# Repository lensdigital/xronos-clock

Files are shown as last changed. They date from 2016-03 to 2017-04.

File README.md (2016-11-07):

Xronos (from greek Χρόνος [kronos] which means Time) Clock is not your average Alarm clock.  
It’s open source, hackable and customizable device.  
It has a stylish look, hand made, and it Talks! 
Heck it will even tell you temperature inside your room or from a remote sensor!
Xronos has internal backup battery that will allow it to keep time if you forgot to plug in … if it’s just for an hour or … for a year or two!  
All settings are saved to flash memory (EEPROM), so you don’t have to worry about power loss. All your alarm settings and preference will be there when power comes back on!
Since all audio files are kept on SD card inside, you can even change alarm tones, or replace voice prompts with your own
Xronos has 3 cool looking durable arcade buttons that give you simple access to all of it’s features.

Note: Please do not use V2 for Xronos 2 Clock anymore. V2 Firmware is no longer maintained, but V3 will work with Xronos 2 Clock as well as with upcoming Xronos 3 clocks.

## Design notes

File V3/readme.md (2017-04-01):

While there's no release date for Xronos 3 clock (I need financing to do a run of new LED displays), I rewrote most of the code and it's now compatible with Xronos V2!
*** Firmware V2 is no longer suppored to maitananed ***
What's new in V3 firmware:
- Supports both DS3231 and DS1307 RTCs chips
- DST and all US Timezones are now (finally!) supported (init EEPROM to write all TZ rules).
- Supports both RFM12b and RFM69w Trancievers (although RFM69w can cause clock to lock up due to SPI conflic with SD library)
- Radio settings (such as frequency, node IDs, etc.) can now be changed in Setup menu
- Most definitions moved to xronos3.h file for cleaner look
- Si7021 temperature and humidity internal sensor now supported
- Supports SoundZ library (audio playback from SPI Flash, only compatible with Xronos3 board). WaveHC no longer used by Xronos3 clock, only for Xronos2
- Button logic was rewritten, holding INCR button for 2 seconds will activate accelerated incrementation in settings of the time, alarm, etc.
To use code for Xronos 2.1 clocks, just uncomment "#define XRONOS2" from main file as well as HT1632.h 
You must initialize EEPROM to write all Timezone rules to it. Do it by either uncommenting initEEPROM() in setup function or thru the menu.
If using RFM12b library with Xronos 2 Clock, please repalce RFM12b.h file with file included in this repository
You will also need a timezone library (https://github.com/JChristensen/Timezone).

NOTICE: To compile code you need Arduino IDE 1.6.10 or higher. It won't work in previous versions.
To upload firmware hex file directly, you will need AVRDUDE version 6.3!

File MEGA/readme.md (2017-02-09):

Expermiental firmware for Xronos Mega Clock (Four 24x16 LED Matrix screens(single color), GPS)

Uploading instructions (Windows):
Upload via FTDI or similar USB to Serial adapter (6 pin).
You can either use Arduino IDE 1.6.10 with included sketch (make sure you have all required libraries)

To upload hex firmware:
  - copy AVRDUDE version 6.3 to know location (i.e. C:\Xronos\AVR). Are required files included with Arduino IDE 1.6.10
  - save all *.bat and *.hex files to some folder on your computer
  - modify update_xronos.bat and specify AVRPath and AVRConfig paths if different.
  - Run start_here.bat and specify COM port of FTDI adapter

Issues:
  - Currently (version 09) user options settings affecting scrolling are not working yet.
  - There might be issue with RGB LED indicator not working correctly
  - When settings hours, date might change, so always check date after settings hours. If you usign GPS, clock will set itself correctly.

GPS and Serial:
  PLease keep in mind that GPS uses same Serial (RX) port as FTDI programmer. This doesn't affect programming clock but please be aware of following limitations:
  - When FTDI adapter is plugged in, GPS will not communicate with clock
  - When GPS function is enabled in menu, you will not see serial output from clock (disable it to see debug info)

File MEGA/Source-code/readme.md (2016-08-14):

Arduino sketch, compatible with Arduino 1.6.10

Requires followign external libraries:
  - Time
  - DS1307RTC (same library works with DS3231 as well)
  - DallasTemperature
  - IRremote (not to be confused with Arduino Robot IR library)
  - TinyGPS
  - Timezone
  
Use following Hardware profile: 
"maniacbug" Mighty 1284p 16Mhz using Optiboot

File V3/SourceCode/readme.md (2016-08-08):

Arduino Source Code for Xronos 2/3 

Note this will only work with Arduino 1.6.10 and probably higher.

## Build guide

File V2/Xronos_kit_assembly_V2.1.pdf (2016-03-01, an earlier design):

# Kit assembly

# What's included:

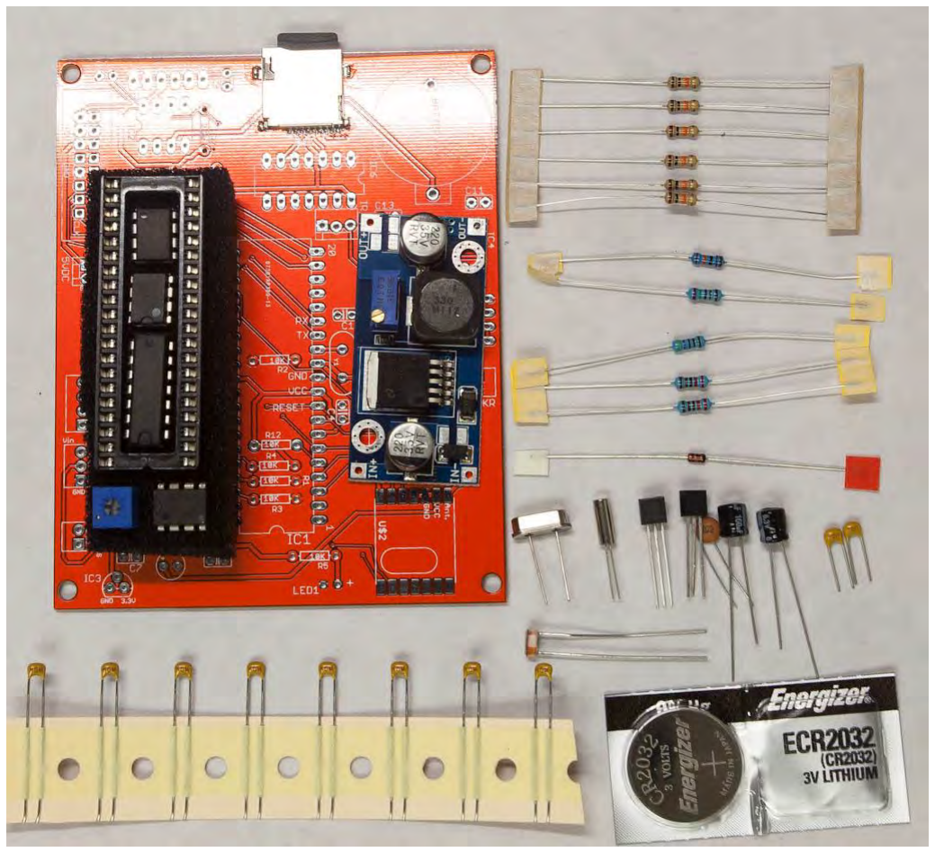
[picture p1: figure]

- Antistatic bag contains:
- ICs on foam block:
- ATMega1284p microprocessor w/ firmware (40 pin)
- 40 pin IC socket

- SN74AHC125N Quad buffer(14 pin)
- DS1308 RTC (8 pin)
- MCP4921 DAC (8 pin)
- TS922IN OpAmp (8 pin)
- Trim pot (10K)
- PCB Board w/ soldered microSD socket and 256Mb microSD card
- CR2032 3 V battery
- Power supply module
- 16 MHz Oscillator crystal

- 32.758Khz Oscillator crystal
- 2x100uF electrolytic Capacitors
- DS18B20 temperature sensor IC
- 3.3V volt reg IC (Yes looks almost identical to DS18B20)
- 8 pcs 0.1uF ceramic caps (104)
Can by two types. Either yellow “dipped”

or orange:

- 2 pcs 22pF ceramic caps
Can by two types. Either yellow “dipped”:

or orange:

- 0.01uF ceramic capacitor (103)

- Photoresistor
- Diode 1N4148
- 6 pcs 10K resistors (ceramic)
- 2 pcs 2.2K resistors (metal film, bluish color)
- 100K resistor (metal film, bluish color)
- 1.5K resistor (metal film, bluish color)
- 4.7K resistor (metal film, bluish color)
- Bag with headers:

- Battery holder
- 2x8 IDC box header
- DC jack
- 6 pin male pin 90 degree header (FTDI)
- 3 pcs 2 pin headers (for power, spkr, photo sensor)

- 4 pin header (for buttons)
- 3 pin header (for temperature)
- Small button (reset)
- Bag with nuts and bolts (hardware)
- 4 pcs 8-32 3-1/2" machine screws (longest screws in package)
- 4 pcs 8-32 Acorn nuts
- 9/16" 4-40 machine screw (longest of 4-40 screws)
- 4 pcs 1/2" 4-40 machine screws (slightly shorter than 9/16”)
- 10 pcs 4-40 5/16" machine screws

- 10 pcs 4-40 3/16" machine screws (shortest of 4-40 screws)
- 6 pcs 1/4" 4-40 alum hex standoffs (shortest)
- 4 pcs 3/8" 4-40 alum hex standoffs (longest)
- 5 pcs 4-40 hex nuts
- Cables:
- 2 pcs two color (polarized) 2 wire cables w/ plug (wires of various colors, one always striped)
- 2 wire same color cable (yellow) w/ plug
- 2 wire 2 color thick cable without plug
- 4 wire flat cable w/ plug (colors may differ)
- 3 wire flat cable w/plug (colors may differ)

- Single 6" wire (yellow)

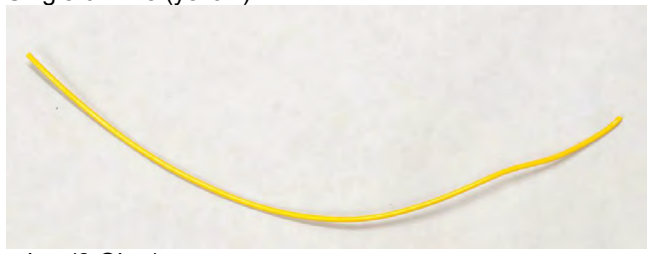
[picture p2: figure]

- Speaker (8 Ohm)
- 3 Arcade buttons
- Enclosure:
- Back

- Front
- Faceplate
- Top
- Bottom
- Left (maintenance door)

- Right (w/ speaker holes and DC jack hole)
- 16x32 LED Display
- DC Wall power supply
- Q-tips

Infrared Kit (Optional)
- 3-pin header
- 3 wire flat cable w/plug (colors may differ)
- IR Receiver (38kHz)
- Remote control

RFM Kit (Optional)
- RMF12B Receiver (915Mhz)
- SN74AHC125N Quad buffer(14 pin)

•
- 10K resistor
- Wire antenna

# PCB Assembly

Note: Some components (diode, electrolythic caps, ICs) are polarized and have to be inserted/soldered right way. Failure to do so will result in board damage!
Resistors and ceramic disk capacitors are not polarized and doesn't mattered which way solders.
Parts:
- All parts contained in antistatic bag (see “what’s included section for all parts descriptions and pictures)
- All parts contained in headers bag (see “what’s included section for all parts descriptions and pictures)

## Required tools/supplies:

- Good Soldering iron with small tip
- Resin core solder (thin diameter, i.e. 0.032”)
- Small Diagonal cutters (Xcelite are best!)

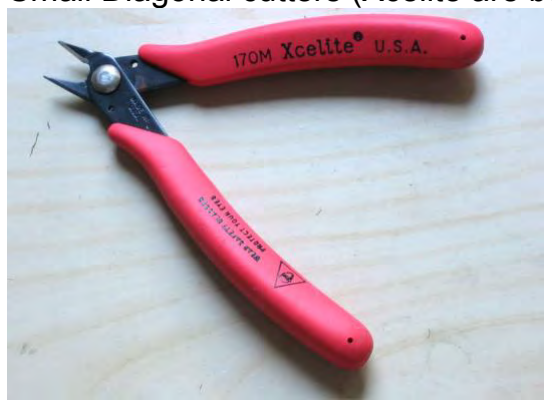
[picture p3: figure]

## Recommended tools:

- Locking metal tweezers. I HIGHLY recommend getting one if you don’t have it! One of the most useful tools during assembly. It will hold tricky components in place and take damaging heat away from ICs.

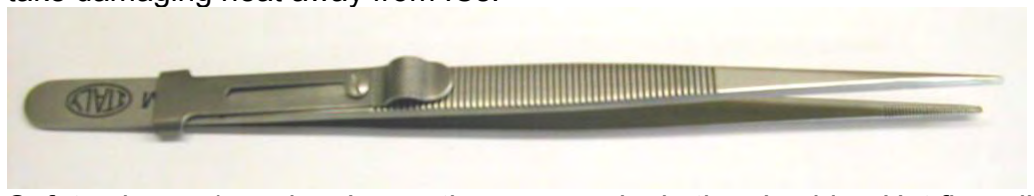
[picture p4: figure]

- Safety glasses/goggles. I wear them every single time I solder. Hot flux will splatter and can damage your eyes. You cannot replace your eyes!
- Wire stripping tool for small gauge wire (AWG24-30)
- Needle nose pliers
- Soldering vice or 3rd hand tool
- FTID Adapter (to check if your board is working in step 1
- Fumes extractor

Assembly process
Order you assemble board is up to you. I’ve organized in parts to make it easier to check your work and troubleshoot before you go too far. For example Part I describes minimum number of components needed to get microprocessor going which you can check with FTDI Adapter (not included). There’s nothing worse than spending 2 hours soldering everything and then finding out that you put a capacitor wrong way in Part II. Note: Only one 40 pin IC socket is included, however it’s totally ok to use your own IC sockets for other chips, as it will make soldering process safer and you’ll be able to reposition ICs in case you inserted it wrong way.
Part I: Microprocessor
1. Align 40 pin socket notch and insert into PCB. Flip around and making sure all pins are fully in solder 2 from opposite ends. Insert into wise and solder rest
Tip: Set iron to hot temp (374C) Solder in rows, clean tip after each row (20 pins)
2. 10K Resistors
1. Unpackage 10K resistors
2. bend legs at base to straight angle
3. insert to R1,R2,R3,R4,R9, R12 bending leads outwards after each so they stay in.
Note: It’s difficult to see R1 location because label is blocked by IC socket. R1 is located between R4 and R3. To make things easier ALL resistors that fit inside IC socket are 10K resistors!

4. Turn PCB around and solder all

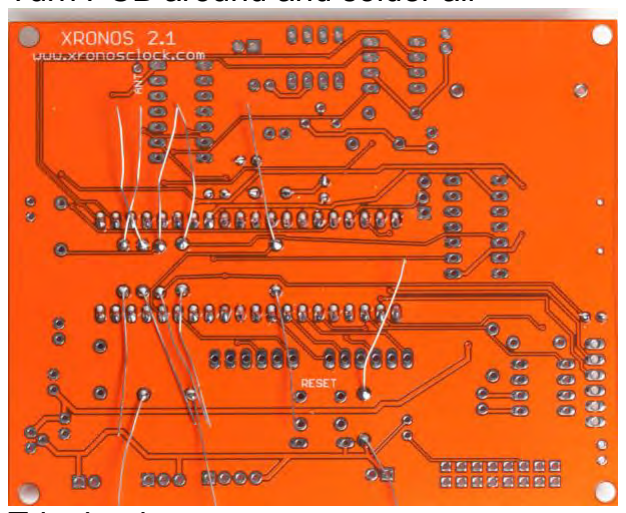
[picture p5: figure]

5. Trim leads
3. Insert Y1 16Mhz OSC
4. Insert C1 and C2 22pF ceramic capacitors (marked as 22 or 220)
5. Insert C3 and C4 0.1uF ceramic capacitors (marked as 104)
6. Solder above and trim leads

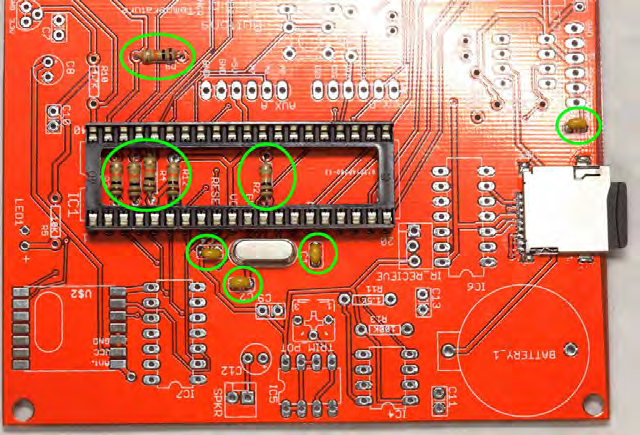
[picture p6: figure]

Picture above shows R1-R4,R9,R12, C1-C4 and Y1 soldered.
7. Take diode D1 and note which side has black ring! Alight it as marked on D1 silkscreen image, insert, bend leads, solder, trim. Failure to align it right way will prevent uploading firmware in the future.

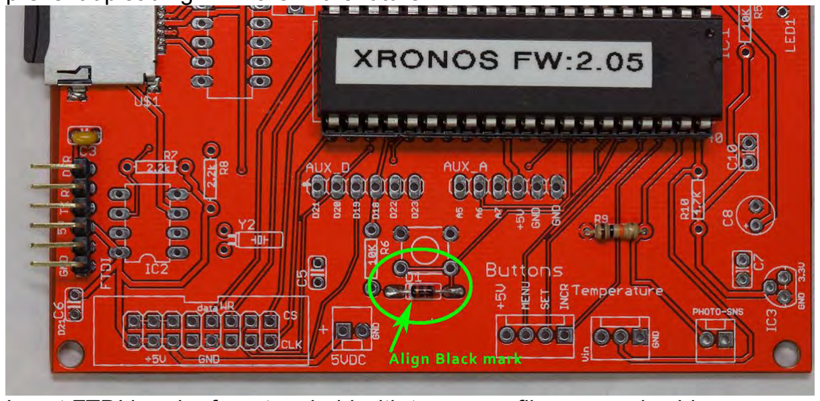
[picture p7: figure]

8. Insert FTDI header from top, hold with tweezers, flip over and solder
Tip: Use very high temp setting on iron, especially for ground pins.
9. Take microprocessor chip and bend all pins slightly inward so it will fit 40 pin socket. I usually hold it by edges, press one side of pins flat on the table and push slightly until the bend, just a tiny bit. Make sure you keep pressure even. Do this on the other side until chip’s leads align with socket holes.

VERY IMPORTANT, align chip correctly, first pin is where notch is, it should resemble outline on the PCB board. Now carefully insert chip and press evenly until it slides in. Look close to see if any bins bent or came out of socket (if you find any remove chip with chip extractor or flat screwdriver and straighten pins.
10.If you have FTDI adapter now is good time to check if board is working at this point. Connect it to computer and using serial monitor from Arduino IDE, or any terminal emulator program (set to 115200 baud and correct COM port) you should get message on the screen (i.e. RTC set system time. SD card error.). Don't worry about SD Card error, we didn't assemble all components for it yet :)

If you don’t see any message, and you sure your FTDI adapter is working, check if chip is aligned correctly. Check all components. Refer to schematic on xronosclock.com site. Or ask us on forum for help.
Part II: microSD reader and Audio
1. Solder C13 0.01uF (code103) ceramic capacitor. Please note this one is different from the rest of ceramic capacitors!!!
2. Solder 6 remaining 0.1uF capacitors (code 104) to C5, C6, C7, C9, C10, C11 Warning! C13 IS Different value! Do not solder 0.1uf capacitor there by mistake.

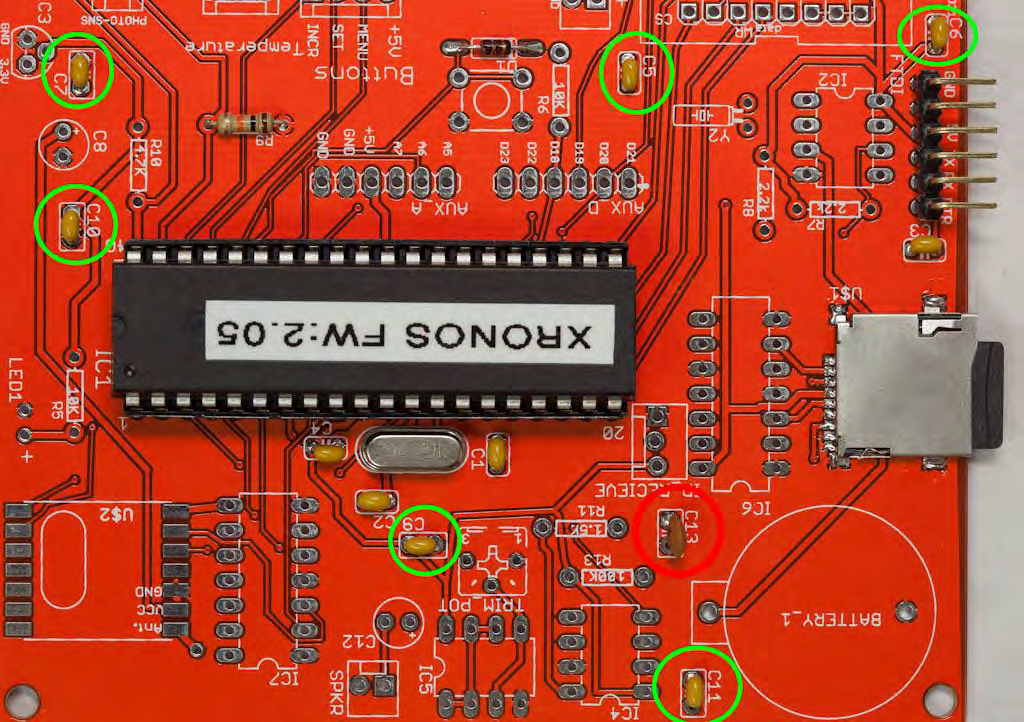
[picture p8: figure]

3. Now we'll solder 2 cylindrical electrolytic capacitors C8 & C12. They are polarized so make sure you put them right way. Longer leg is positive, insert into hole marked +. Negative part also has white stripe on the body. See picture below:
4. Now solder 3.3V voltage regulator to IC3. It looks identical to temp sensor, so read marking, it will say 1700. It's important to insert it right way, follow outline on PCB.
Warning: IC3 is sensitive to static, wear antistatic wrist band!
Warning: Do not overheat! Use lower setting on soldering iron (no more than 360

5. C)
6. Take Quad buffer chip IC6 (SN74AHC125N) and bend its legs slightly inward (just like with main microprocessor) until they parallel to each outer so it will fit the board. Pay attention to orientation notch, it's very important!

Note: It’s ok to use IC Sockets for all chips, but we don’t include them in the kit. Warning: IC is sensitive to static, wear antistatic wrist band!
Warning: Do not overheat! Use lower setting on soldering iron (no more than 360C) and/or use locking tweezers to hold it and conduct heat way.
7. Solder IC5 (TS922IN). Use same precautions as with above.
8. Solder IC4 (MCP4921). Use same precautions as with above.

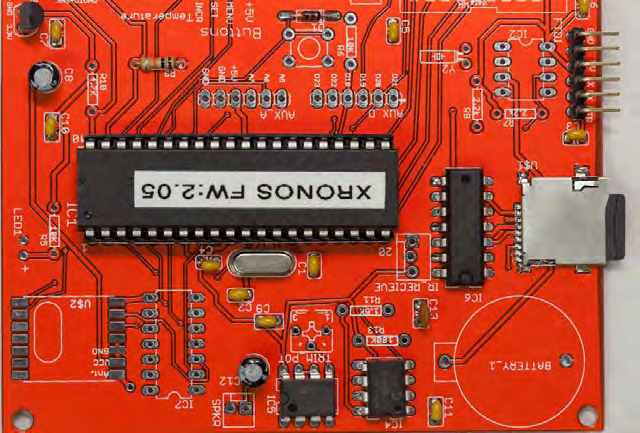
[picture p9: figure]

9. Insert and solder 3-pin blue trim pot
10.R13 and R11 are blue colored resistors. R11 is 1.5K (Brown, Green, Black, Brown, Brown) and R13 is 100K (brown, black, black, orange, brown). Solder these.
11. Next we will solder 2 pin header for speaker, and one for power (both marked on PCB). Take special attention at polarity of these, especially power connector! Smaller rectangle indicates plastic long back of the header. Note how power header faces way from edge of the board, and speaker go other way. See picture.

You can now test Audio! If you soldered connector to speaker and assembled power supply board (or you can power via FTDI) connect them and you should hear startup sound! Adjust volume by turning trim pot (clockwise for louder). Ideally bring it to full volume.
Part III: RTC and rest
1. Solder remaining 3 blue resistors:

1. R7 & R8 2.2K (red, red, black, brown,brown)
2. R10 4.7K (yellow, violet, black, brown, brown)
2. Solder Y2 socillator (small metal cylinder)
3. Solder IC2 (DS1307) RTC chip. Orient it correctly! I made mistake of soldering it wrong way once and it started to smoke!

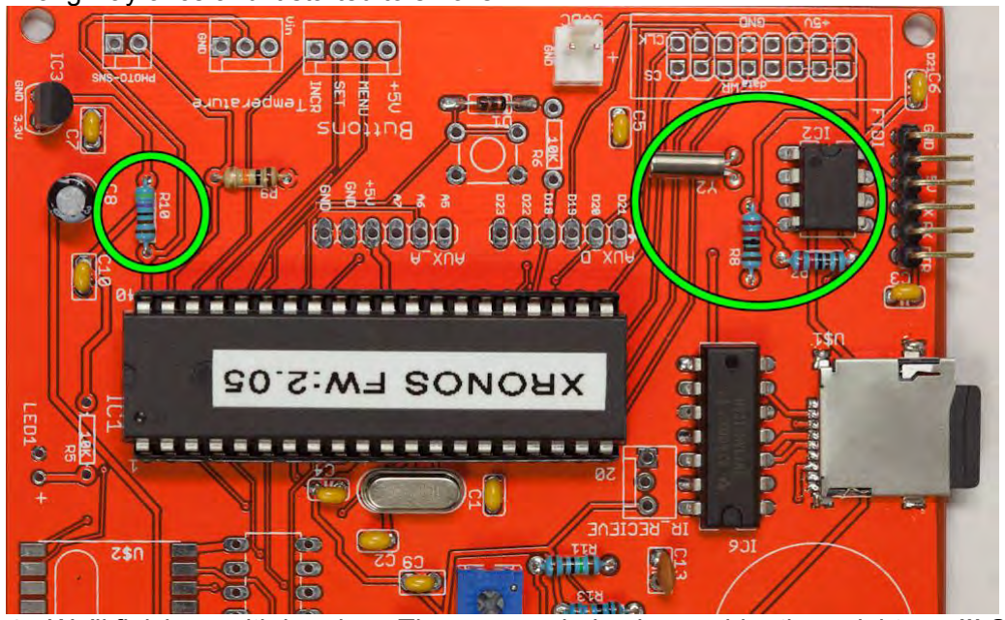
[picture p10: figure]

4. We'll finish up with headers. These are polarized, so solder them right way!!! Set soldering iron temp night, as these (especially IDC header) can be tough to solder. Also use locking tweezers to hold them in place.
1. Start with 2-pin Photo-sns header
2. Then do 3-pin (Temp) and 4-pin (buttons) headers next to it.
3. Solder big 8x2 IDC header
4. Solder battery holder. Negative terminal will require a lot of heat so set your iron to 390C

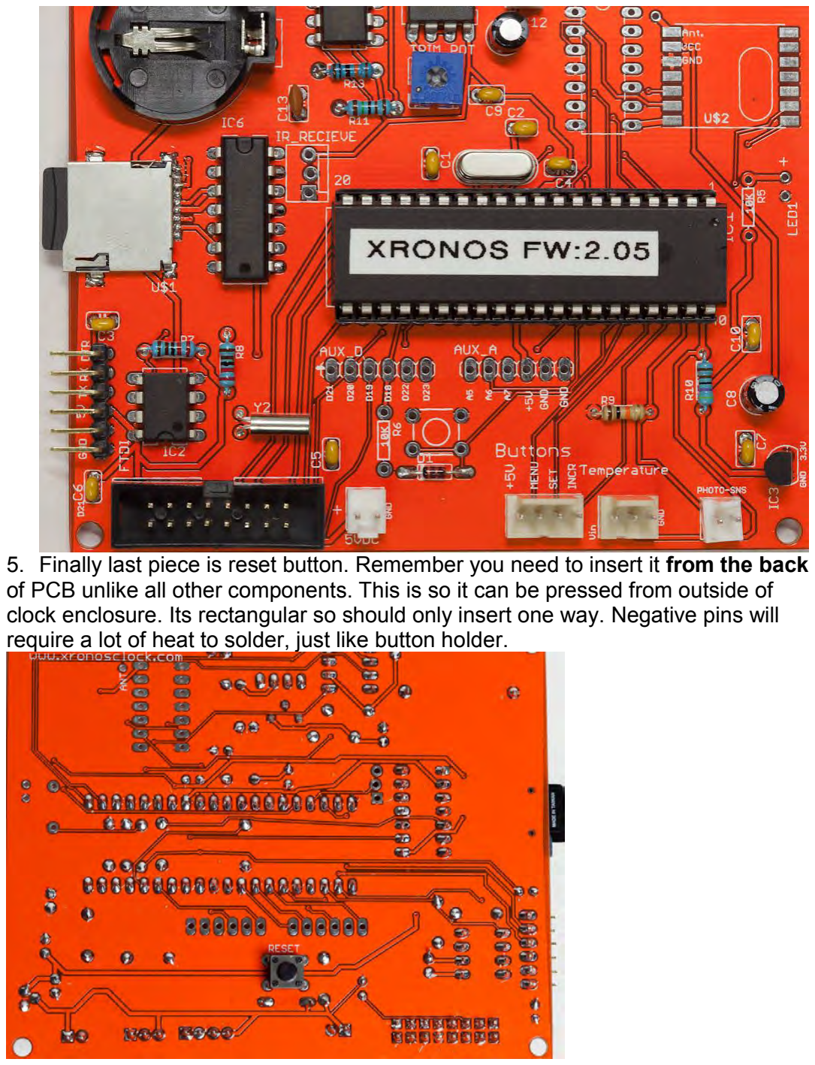
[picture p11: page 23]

5. Finally last piece is reset button. Remember you need to insert it from the back of PCB unlike all other components. This is so it can be pressed from outside of clock enclosure. Its rectangular so should only insert one way. Negative pins will require a lot of heat to solder, just like button holder.

Part IV: OPTIONAL RM12B receiver and IR receiver
Please note: You must have Firmware version 2.06 or later in order for these accessories to work!
1. Solder R6 (10K) resistor

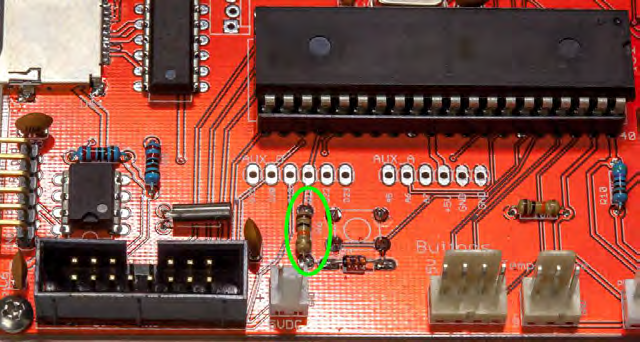
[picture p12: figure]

2. Note how bottom of RFM12B module will have an oval outline that matches one drawn on the PCB. You will follow that outline.
3. Do not place module on board yet. First put drop of solder on one of the pads on the PCB
4. Now place RFM12B module on board (following outline). Melt solder that you applied in step two and adjust module at the same time so all pads are aligned. Solder will hold it in place.
5. Now solder all pins.
6. Take Quad buffer chip IC7 (SN74AHC125N) and bend its legs slightly inward (just like with main microprocessor) so it will fit the board. Pay attention to orientation notch, it's very important!
Warning: IC is sensitive to static, wear antistatic wrist band!
Warning: Do not overheat! Use lower setting on soldering iron (no more than 360C)
and/or use locking tweezers to hold it and conduct heat way.

7. Strip wire antenna from one end and solder it thru “antenna” hole on PCB

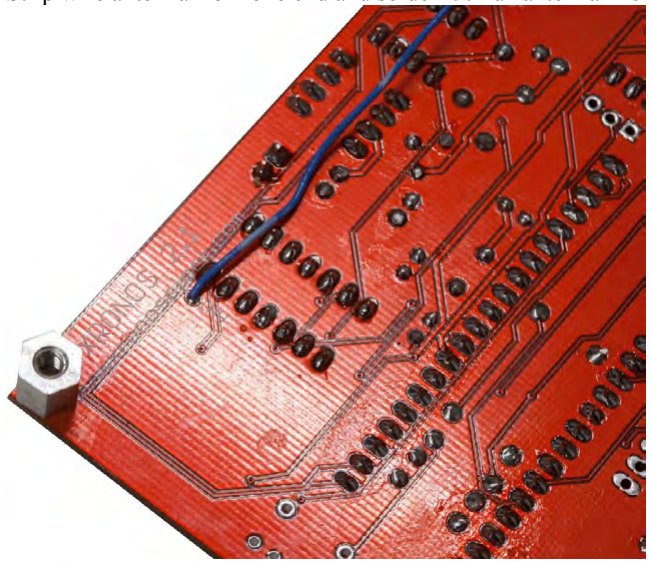
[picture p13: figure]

8. Finally if you purchased IR kit, solder 3 PIN header to IR_RECIEVE following board outline.

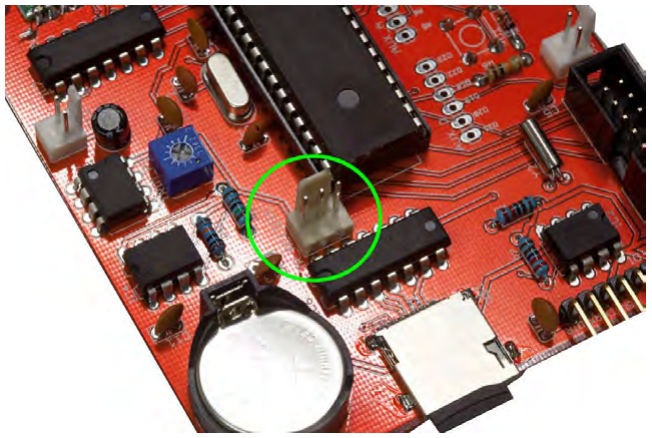
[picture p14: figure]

# Temperature sensor

1. Find black 3 pin cylindrical IC that's marked DS18B20. Note that it looks identical to 3.3V regulator in your kit so don't mistake one for another!
2. Shorten leads by cutting them off half way. Spread leads a little.
3. Set iron to lower heat and tin each lead
4. Take 3 pin flat and solder to sensor in correct order cable (colors vary, please check which pin goes where by following image below). Looking at flat face of the cylinder, left most lead is ground (despite it being marked with “+” on the chip), it goes to brown wire. Then rest will go in the order they are in the cable. Make sure you solder wires as parallel to the leads as possible. Pull slightly to make sure they are holding. You can also use heat shrinking tube if desired, but hot glue will keep them

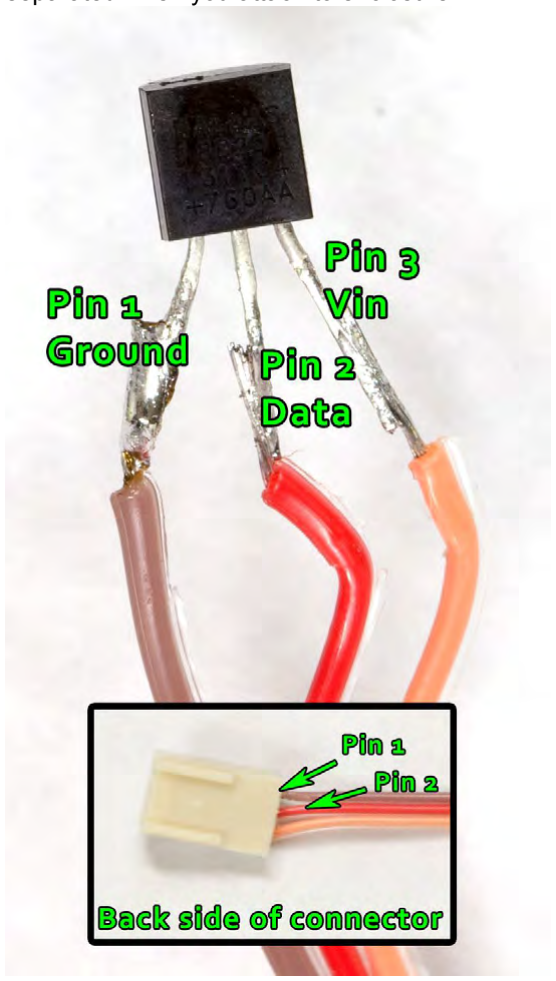
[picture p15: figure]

separated when you attach to enclosure.

# Power supply board

1. Take thick 2 wire two color cable, strip and tin both ends
3. Solder cable to DC jack as shown. If cable is Red/White, red will be positive. If its white and black, white is positive.

Note (on the pic above) how flat metal band is on the left side when positive terminal is on top.

4. Solder other two ends to power board to the IN part, using correct polarity.

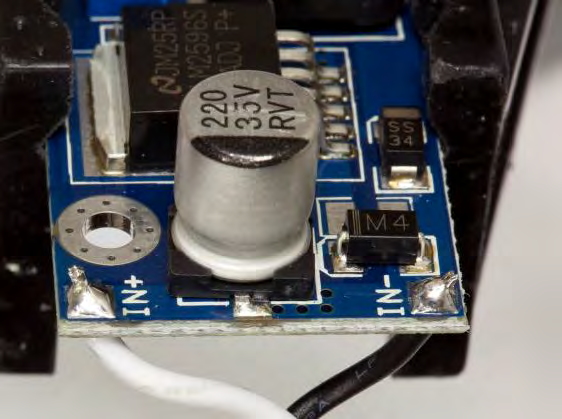
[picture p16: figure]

4. Take 2 wire two color cable (with plug already attached) and solder to the "OUT" holes on the power board. Solid color must go to OUT+, and striped to OUT-

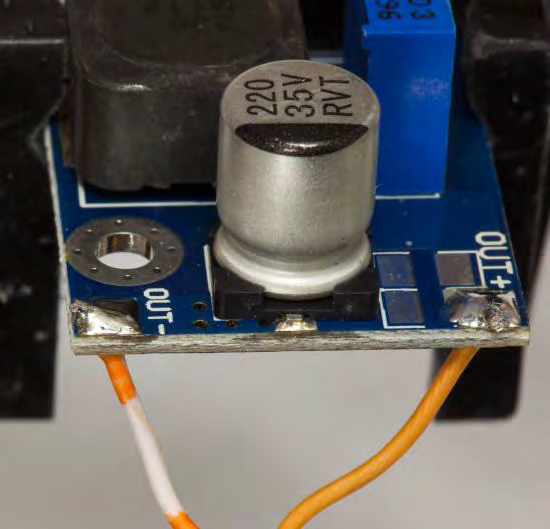
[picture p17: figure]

5. Plug dc wall adapter to DC jack and with multimeter verify correct polarity and output voltage of 5V. If voltage is off, adjust screw of the blue pot (blue block) with small flat screwdriver.

# Photo sensor

1. Trim leads
2. Tin leads
3. Take cable that has two wires of same color (yellow) and solder to photoresistor

# Speaker

1. Tin speaker leads
2. Take two color two wire cable and solder, with solid color wire going to +

Note: Some speakers do not have polarity markings! In this case solder as in picture above, negative wire on top, positive on the bottom.

Test board
Now is a good time to test your circuit board if you haven't.
1. Plug in speaker cable into PCB Speaker jack (on top).
2. Plug in power supply board into PCB power jack (marked PWR)
3. Connect wall DC adapter to DC socket. Clock should make startup sound.

IR Receiver (Optional)

1. Trim IR receiver’s 3 leads in half
2. As show in the picture below solder cable’s pin 1 to IR receiver’s pin 2 (middle)
3. Solder cable’s pin 2 to IR pin 1
4. Finally solder remaining wire.

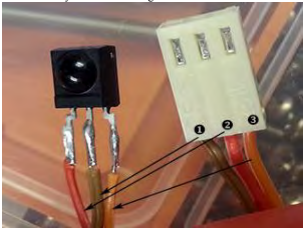
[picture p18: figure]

# Paint enclosure lettering

This is the most tedious part. You’ll need some patience but don’t worry, it’s not that hard You will need to get your own white Acrylic water based paint, as it’s not included in the kit. You can buy small bottle in local Walmart or arts supply store (I use Craft Smart paint (http://www.michaels.com/Craft-Smart-Acrylic-Paint-2oz/cp0396,default,pd.html) from Michaels) for about $0.50

1. Peel protective paper from both sides of top (button) panel
2. Gently scrape remaining paper from letters
3. Wet q-tip in water and clean laser etched letters
4. Squeeze paint to a pallet (piece of paper, plastic, etc).
5. Dip another clean q-tip to paint and start filling in letters. Make sure you completely fill in all crevasses but try not to leave too much paint in other areas.
6. Let it dry for few minutes.
7. Now take a piece of soft rug, wet it slightly with water and start wiping off paint. Only paint should be left is inside etchings. Take a clean dry piece of soft cloth and wipe haze left by damp cloth
Tip: I recommend using 2 pieces of soft clean cloth, while you can also use paper towel it might scratch plastic!
8. Repeat 5-7 at least one more time, until text is clearly visible and looks nice.
9. Now repeat steps 1-7 with back and right panels. These have less engravings so you might not have to fill them more than once like with top panel.

# Hot Glue

You will need to have a hot glue gun and some hot glue sticks for this. Any kind should work.
Before you begin keep in mind that:
1. All glue goes on the inside of the panels, not visible after you assemble enclosure.
2. When gluing speaker and nuts, avoid some areas that will jam enclosure. These are show in the pictures below as red rectangles. Good areas are show as green.
Tip: If you need to trim hot glue after it solidified use sharp razor blade. You can completely remove hot glue with heat gun (but keep in mind that speaker might get damaged by heat gun).
1. First glue speaker to inner side of right panel. Apply hot glue in several places but avoid areas shown in red on the picture. Green areas are good. And do not get any in the holes!

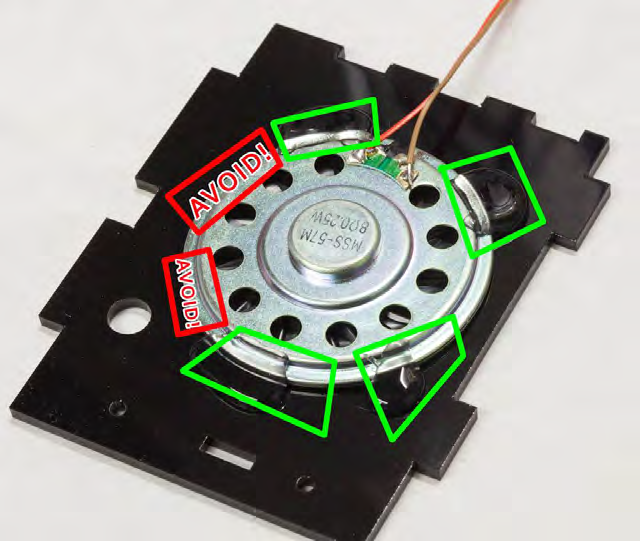
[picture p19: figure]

2. Set that panel aside to cool down
3. Insert temperature sensor into hole on back panel as shown (you must do it on inner surface). Put something under the panel (like a match) so sensor can protrude slightly outside. Bend leads and spread slightly so they not touching each over. Apply hot glue and let it cool and solidify.

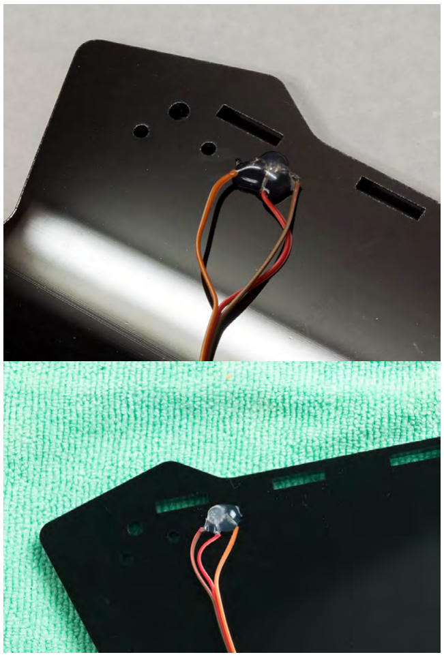
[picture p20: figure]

4. Glue photo sensor to top panel. From inside alight it with oval hole that’s shaped like sensor and try to level so it's flush with outside surface. Bend leads to opposite sides. You might want to use locking tweezers to hold one of leads. Apply glue. If you used tweezers after one side solidifies, remove them and apply glue to other side where tweezers were.

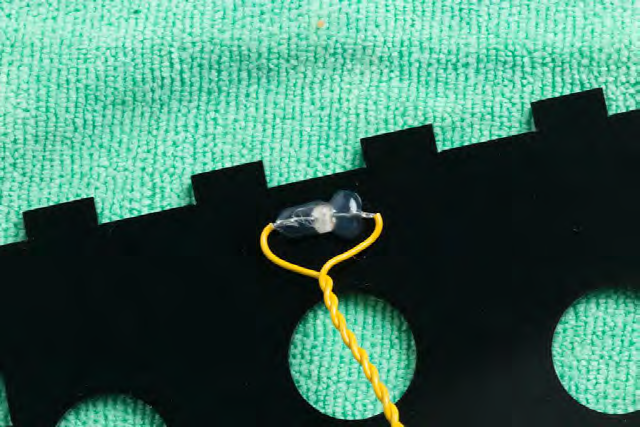
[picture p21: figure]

5. Now a tricky part - gluing 4-40 nuts. You can skip it, but it will be harder to assemble/re-assemble clocks if nuts are not held in place by hot glue.
1. Take bottom panel (one with ventilation holes) and note which surface is inner (it's marked!). Remove paper from that surface only!
2. Attach right (speaker) panel to bottom as shown, with two nuts and two 1/2 4-40 screws. On picture below I’ve indicated which way is front of the clock and which is back. See how bottom panel has only two tabs (this is front) and other side has four tabs (back). Right panel has two smaller tabs facing forward. This will help you identify to which side you need to place glue.
3. Attach left panel to button on the other side.

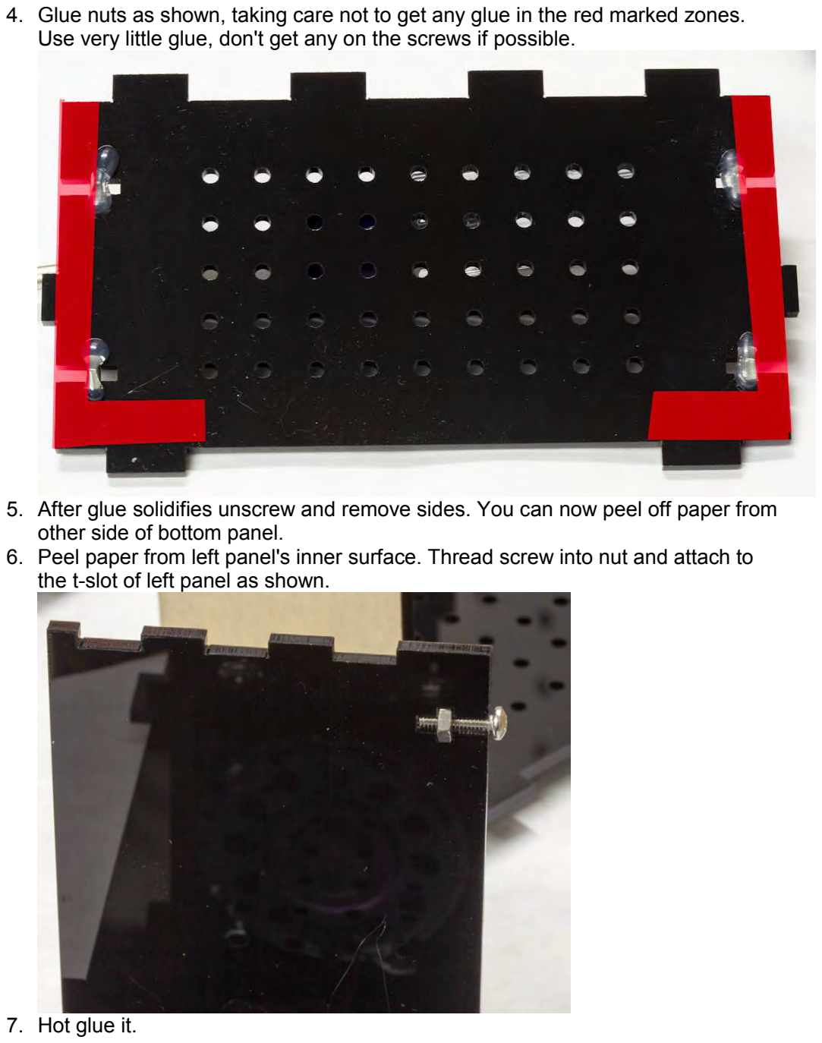
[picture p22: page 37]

4. Glue nuts as shown, taking care not to get any glue in the red marked zones. Use very little glue, don't get any on the screws if possible.
5. After glue solidifies unscrew and remove sides. You can now peel off paper from other side of bottom panel.
6. Peel paper from left panel's inner surface. Thread screw into nut and attach to the t-slot of left panel as shown.
7. Hot glue it.

Optional: RF Receiver

1. Locate bottom of the LCD panel (bottom is where all the plugs are).
2. Turn it around so LEDs are facing you and place large drop of hot glue just below LEDs
3. Just before it solidifies Place RF receiver (with attached wire) on top of it with round “window” facing you. Be careful not to get any glue on bulging part.
Final result should look similar to the picture above.

# Buttons

Note: Your buttons might looks slightly different depending on manufacturer. Some have contacts on opposite ends with 2 holes, some have contacts on same size in line with just one hole in each.
1. Cut single yellow 6" wire in half
2. Strip and tin ends, taking care to not leave too much solder on them (so they can easy go thru button round holes
3. Take middle (set button), thread both wires thru one lead (same hole) and solder. Cut off excess
Note: your button might not have hole large enough for 2 wires. In that case you will need to solder wires together and then to the button’s lead.
4. Insert all buttons into top panel (in the right places) until they snap in place.
5. Solder one of the yellow wires coming out of middle “Set” button to white “Incr” button’s lead.
6. Get 4 wire flat cable. By looking at plug determine which wire goes to pin 1 (usually violet or red). This is your +5V line. Next to it is menu, set and finally incr signal wires.

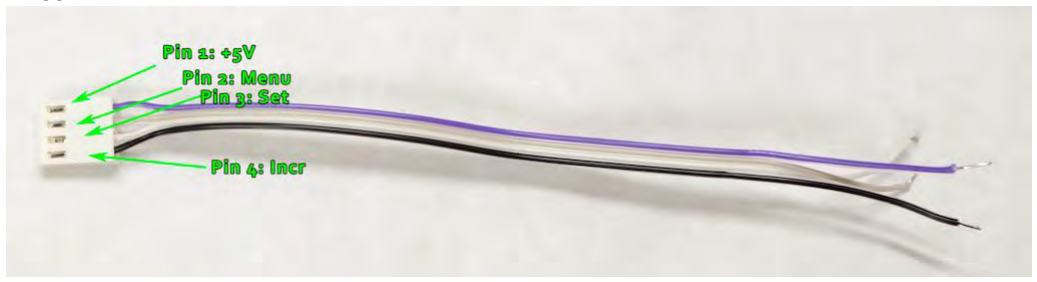
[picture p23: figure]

6. Insert pin 1 wire together with one of ends of yellow wire into same lead's hole of black "Menu" button and solder. You are basically connecting power line to all buttons.
8. Now solder "menu" wire to second lead of "menu" button.
9. Solder "set" wire to second lead of "set" button
10.And finally solder "incr" wire to second lead of "incr" button.

Prep circuit boards for mounting.

You going to attach aluminum hex standoffs to boards with 4-40 3/16" screws (they are shortest screws in the kit). Do not tighten any screws, leave them loose for now so standoffs cam move around slightly.
1. Remove LED screen from box and antistatic bag.
2. Peel off plastic squares from front surfaces.
3. Attach four 3/8" hex standoffs (longest ones) to the LED display with 4-40 3/16" screws. Standoffs should be on the front side.
4. Attach two 1/4" hex standoffs to power supply with 4-40 3/16" screws.
5. Attach remaining 4 standoffs to main PCB' back side
Mount LED screen
1. Pay close attention to front panel. Its hard to say where top and bottom or back and front is, so we marked it with arrow on the FRONT side pointing towards top. You will attach LED from opposite side. Bottom of LED is where connectors are.
2. Align it and remember how it should be.
3. Now take protective paper from BACK (unmarked) side. It is better to leave front masking paper on for now.
4. Screw it LED in through the holes with four 4-40 5/16" screws. Some screws might not alight with hex standoff holes. That's why we didn't tighten them. Move standoffs until screws fit. Tighten screws on both sides.
5. Now we can peel masking paper from front face. It's held by screws to, so star peeling until you close to 1st screw, unscrew it a little and you should have no problem peeling paper from under it. Once it's clear of paper, screw it back in, then do hex one, one by one. It's actually easier than it sounds.
Tip: You can skip this step and leave paper to protect clock face until enclosure is nearly fully assembled!

# Mount PCB

1. Align PCB as shown (temp cable under for better cable managment)
2. Screw to the back panel with four 4-40 5/16" screws. If any holes don't align move standoffs slightly.
3. Tighten all screws, but not too hard.
4. Plug in temp sensor.

# Mount Power Supply board

1. Align as shown (thick cable on top).
2. Attach to panel with two 4-40 5/16" screws
3. Unscrew nut from DC plug, insert plug into right (speaker) panel add washer and secure with nut.
4. Plug in 2 pin power connector to PWR plug on PCB.
Note: Speaker, Power and Light sensors have same kind of plugs on PCB. Make sure you use correct one!

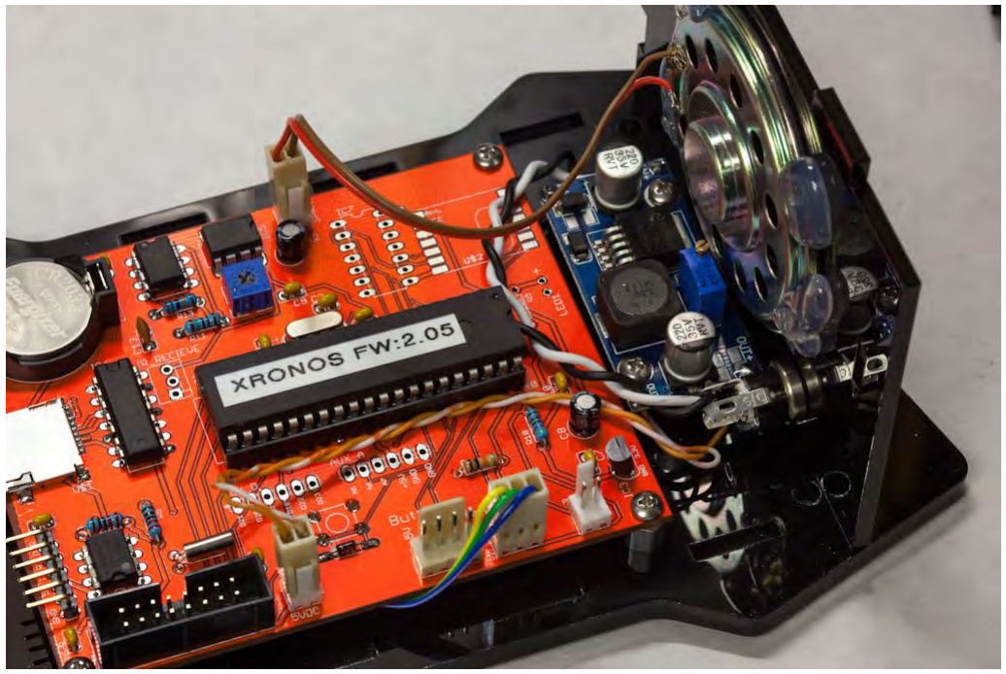
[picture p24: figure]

# Assemble enclosure

Warning! Acrylic is somewhat fragile. Do not force tabs into slots, you might break them.
1. Lay back panel on the table. You will insert all other panels into it.
2. Insert right speaker panel into slots
3. If bottom panel still has protective paper, peel it off.
4. Insert bottom panel into back and at the same time its tab should go into slot in right panel. You might have to lift right panel slightly for this.
5. Plug in speaker cable to PCB.
Note: Speaker, Power and Light sensors have same kind of plugs on PCB. Make sure you use correct one!
6. Secure right panel to bottom panel with two 4-30 1/2" screws. Don't over tighten, it's easy to crack acrylic here!
7. Insert top panel with buttons into bottom panel (you might have to raise right panel slightly to get tabs to interlock). Middle button might touch speaker plug. Rotate button slightly so it fits on top of plug, and check light sensor cable so it doesn't get sandwiched between button and plug.
8. Plug in button cable and light sensor cable into PCB
9. We will do left panel at the very end, don't worry about it, it's designed to be detached and re-attached when clock is fully assembled.
10.Take front panel with LED display, bring it close to the rest of case and plug big ribbon cable into PCB.
11.If you purchased IR Receiver plug it’s cable into IR header.
12.Gently slide front panel over until all tabs are in the slots. Do not press hard on it, it should go down effortlessly once everything aligned (wiggle various panels). Tabs will not protrude all the way, that's normal, just check from sides that its sitting ok. If display doesn't go all the way down and " squeaking" it means that hot glue holding nuts on the bottom panel is in a way. You can probably see it from left side. If that's the case you'll need to take bottom panel out and trim glue with blade.
13.Take faceplate, peel masking tape and put faceplate on top of front panel. You might press on it slightly so screws will "click" through openings.
14.Take 4 longest screws (8-32 3-1/2") and thread from the bottom, securing on top with acorn nuts. Easiest way to do it is hang one corner of Enclosure from table edge, insert screw, then expose next corner, etc.
Note: If crews experience much resistance it could be that hot glue holding nuts on bottom panel is on the way. You can either try threading screws thru the glue with screwdriver or trim glue with blade. Ideally these long nuts should go thru enclosure very easy.

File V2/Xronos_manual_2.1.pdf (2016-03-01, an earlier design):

# Xronos Clock Manual

For Xronos Clock V2.1

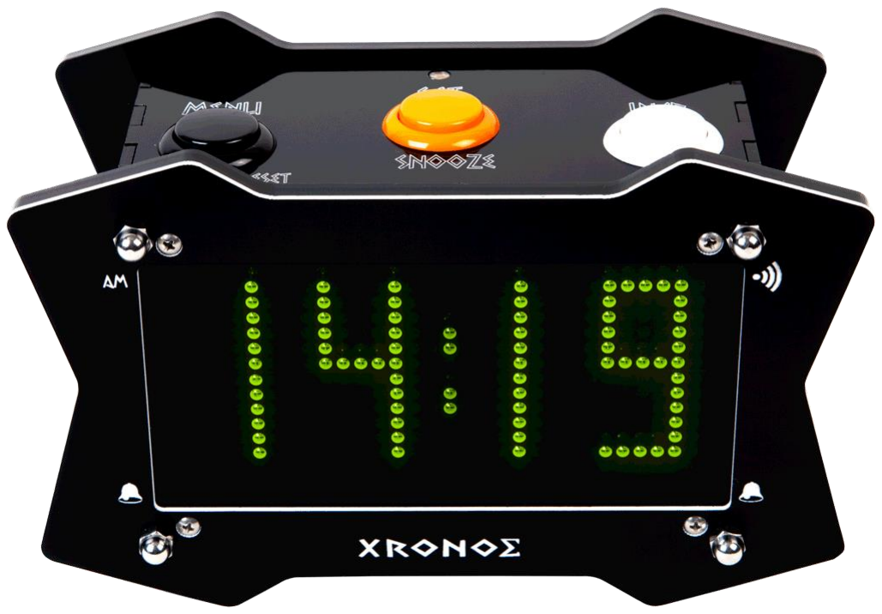
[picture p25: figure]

Foreword.

If you are like me, you’ll probably ditch this manual and start messing with cool arcade buttons. Xronos clock is intuitive and should be easy to figure out. But I see you are still reading, so let’s get on with it, I promise I’ll try not to make this manual look as boring as your average table saw instructions.

Quick start

Xronos clock comes with a good quality AC Adapter that will power your clock and won’t waste too much of power!
Firmly plug in power adapter into wall outlet and DC cable into clock’s right side. Assuming delivery man didn’t drop your package off the truck (is there anything rattling inside clock case?) and you have power in your house Xronos should greet you with scrolling welcoming message and firmware number. If you are real lucky it will even play a startup melody :)
But not to worry, if startup sequence starts to drive you crazy in the future you can turn it off!

Let’s get familiar with Xronos Clock.

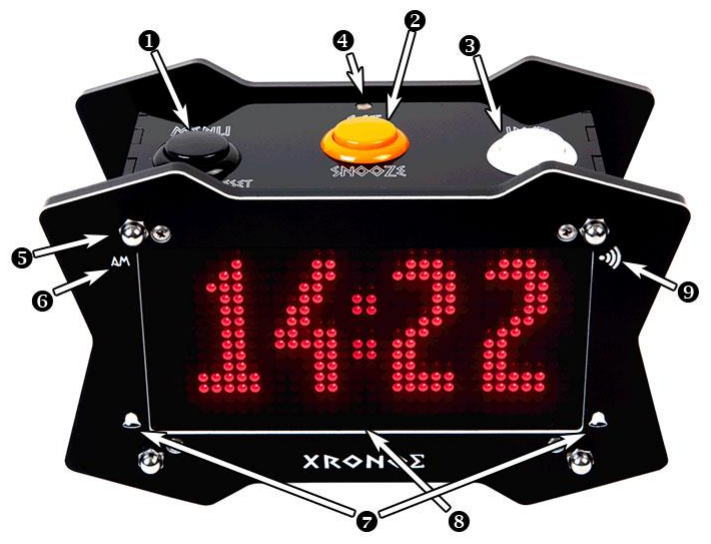
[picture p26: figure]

1 – MENU/ALARM RESET BUTTON 2 – SET/SNOOZE BUTTON
3 – INCR/TALK BUTTON
4 – AMBIENT LIGHT SENSOR
5 – ACORN NUTS (HOLDS ENCLOSURE TOGETHER) 6 – AM INDICATOR (FOR 12 HOUR MODE)
7 – ALARM 1 AND 2 INDICATORS
8 – IR SENSOR WINDOW (NOT SHOWN ON THIS PICTURE) 9 – RFM12B RECEIVER STATUS INDICATOR

Looking at the top of the clock you will find 3 very sleek looking arcade buttons. From left to right they are: MENU, SET and INCR (or Increment), and... well that’s it! What did you expect, a QWERTY keyboard? Each button has several functions.
Go ahead, touch the MENU button! Nice huh? Do it again! AGAIN!!!! :) Ok stop stop. MENU is primary button that will get you into a … *surprise!* menu system. With every press it will go to the next menu item and eventually back to the 1st. There’s no exit out of menu system per say, but don’t panic! If you stop pressing all buttons clock with automatically exit after 5 seconds of inactivity.
After you got into the menu that you want, press SET button to switch between items inside this menu. Then use INCR button to make change to selected item. And no need to “save” settings. All changes are saved into permanent memory (EEPROM) either immediately after pressing INCR button or after clock exits from menu.

Now look at the right side. It’s the one that has a lot of small holes. That’s for the speaker, next to it is opening for power plug.

On the back side, there’s an opening for resetting clock and temperature.

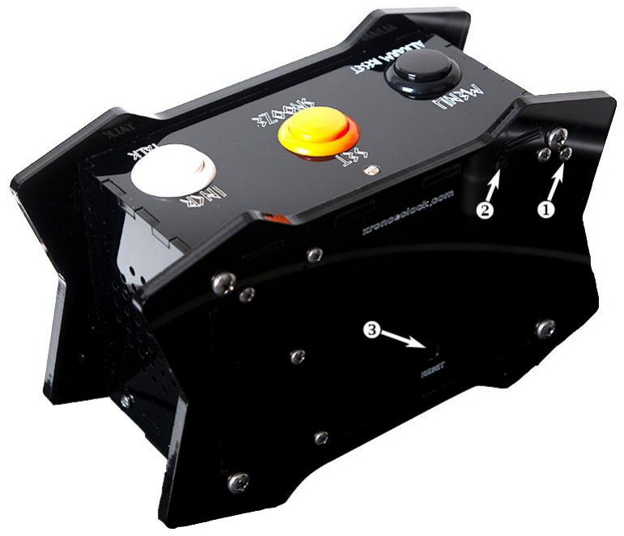
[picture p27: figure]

1 – MAINTENANCE DOOR RELEASE SCREW 2 – TEMPERATURE SENSOR
3 – RESET

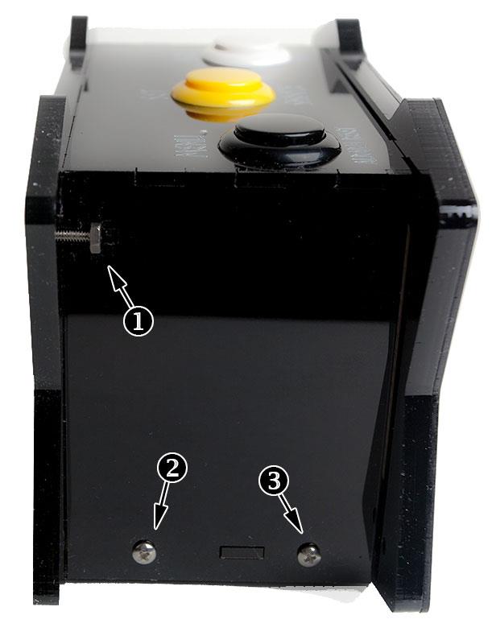
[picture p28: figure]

Left side of the clock has removable panel (held by 3 screws) for easy access to clock interface in case you want to re-program/update firmware, access microSD card (that holds all audio files) or replace clock battery. Yes, clock has internal small coin type battery for keeping time when external power is not available. It should last few years when in use, and much longer than not in use.

Setting Time (and surviving apocalypse)

After everything is up and running first thing you’ll might want to do is to set correct time and date. Out of the box clock is set to 24 hour (a.k.a. military time) mode. If you are more familiar with 12 hour mode (AM/PM) sorry, you are out of luck. Just kidding :) You can change modes by pressing MENU button until you see Settings on the screen. Press SET button. First option will be 12/24 hour mode. Press INCR button to change it if needed.

Hint: When you see something is flashing it means its selected and ready to be changed with INCR button.

Press MENU button again several times until you see Date/Time on the screen. Press SET button to select Hours/Minutes, etc. and INCR button to change it. Don’t fret if you accidently went over current year! Once you hit year 2040 it will go back to 2013. Why 2040? What a silly question! That’s when either world will end or Xronos Clock will become self-aware and will no longer need you (which is the same thing). So please be nice to it.
That’s it, now you should have a grasp of how menu system works, and at the end of the manual you will find especially boring fun schematic of all the menu functions and flows, sorry no pie charts.

Secondary Functions

As I mentioned earlier (were you paying any attention or just mashing arcade buttons?) each button has secondary function. Heck some have even more than 2! Xronos clock is practically Swiss army knife of clocks! Well not really a knife, and not Swiss, but it’s still pretty versatile! Most notable is the INCR button a.k.a. (we have ways of making you) TALK button. When not in any menu pressing INCR button will make Xronos Clock talk. Sorry it probably won’t be most engaging storytelling, but it will tell you current time, date, inside temperature and even what your alarms are set to!
Just briefly press and release this button to hear next item. If you pause for more than 6 seconds between presses it will go back to 1st item (i.e. current time). You can also hold INCR button for 2 or more seconds and once you release it clock will go into continuous talk mode meaning it will tell you time, date, temperature and alarm settings without you having to press button after each item. What you clock says is customizable via User Options menu. There you can choose what you want Xronos to say or not to say. For example you can set it to tell you only date and temperature, but not Time and Alarm settings.
When alarm sounds INCR button can also be used to turn on “please just few more minutes” Snoozing. Actually SET button also turns on Snooze. Either one will let you catch some more zzz’s. That’s pretty much all this “SAD” SET button does when not in the menu :(

Menu button also has secondary functions. You can use it to interrupt scrolling Info Display, and Reset Alarm for current day. Resetting alarm only works if Alarm is currently playing or snoozing.

Alarm Functionality

Your Xronos clock has mighty Dual Alarms.
Each can be set to sound either Daily (Sunday-Monday), Workdays (Monday thru Friday) or on Custom days of your choosing.

Warning: Never set both alarms to same time on same day! If you do, miniature black hole will form 5 centimeters above the clock and will probably transfer you and the planet into 37th dimension. Because time flows in reverse in 37th dimension, clock might not function as expected.

Each Alarm has LED indicator (dot on the bottom left and right of the LED screen). When light is green it means no Alarm is set for current day. When it’s orange Alarm is set for this day (keep in mind light will remain orange thru the day even if alarm already sounded and has been reset). Alarm light will be Red when Snoozing is activated.
Snoozing will silence alarm for 9 minutes, after which it will start sounding again until either Snooze or Reset engaged (i.e. via MENU button). Alarm will reset itself after 1 hour has passed or second Alarm kicked off.
Alarm menu system is slightly different from other menus, and requires master’s degree in nuclear dentistry to fully comprehend. If you set alarm to Custom mode, it will keep going thru Days of Week on the screen until you press INCR button when EXIT is shown. At this point you’ll be able to set alarm time and tone/melody.
There are currently 10 alarm tones/melodies to choose from. First 5 are of escalating type, meaning they will start at low volumes and get louder with each repeat of the sound (eventually reaching ultrasound frequencies, shuttering glass windows, and waking up every dog in the neighborhood *just kidding*). This is best way for a gentle wake up.
Last 5 alarm sounds will always start at full volume, you’ve been warned! :)

Info Display

Periodically you will see a message scrolling across the screen. This is your Info Display. It will briefly tell you date, temperature, alarm settings, winning lottery numbers and last 4 digits of your cat’s social security number. Well not really, just 1st three items. You can customize how frequently you want to see this via User Options menu. You can even turn it off completely. Info Display scrolling can be interrupted any time by pressing MENU button (what a neat button, huh?).

System Settings Menu

From here you can control many “under the hood” global functions of the clock such as setting 12/24 hour mode, Brightness (manual or automatic), color, clock font, sound volume, Fahrenheit or Celsius temperature mode, turn on/off optional RF and Infrared receiver functionality.

User Options Menu.

Very similar to System Settings. In this menu you will be setting misc. options such as what clock will say when TALK button is pressed, or how frequently Info Display will appear and temperature offset. See below about this option.

Temperature Offset

What is it and why it’s needed you might ask? Can it reverse effects of the global warming? Well you see, Xronos Clock components generate some heat. Especially LED matrix. As efficient as LEDs are they still get warm. Higher brightness you will choose, the warmer clock will get inside. This is really nothing to be worried about (we are talking about few degrees above ambient), however because temperature sensor is embedded in the clock case, it will usually show temperature couple of degrees higher than air in your room. Thus comes Temperature offset to the rescue! I recommend setting it to about -2 degrees. If you have another thermometer available use it to calibrate Xronos Clock to a correct temperature using offset.

Optional Features

In order to keep price of the clock down some extra features are available only as add-ons. Currently there are two features: Infrared Remote and RFM12b (radio frequency) transceiver.

Infrared Remote

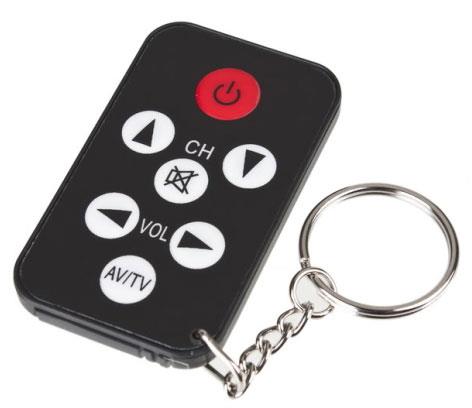
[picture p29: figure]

New to Xronos Clock 2.1 is support for Infrared Receiver and ability to control clock functions with “keychain” remote control.
Remote duplicates functionality of the arcade buttons and additionally gives ability to decrement items (i.e. when setting time you can increase or decrease hours/minutes).
Here’s what each button do:
- Big Red On/Off button: Same function as MENU button
- Mute (crossed speaker) button: Initiates TALK function (announce Time/Date, etc.). Additionally this buttons when held for few seconds starts to reprogram remote. More on this later.
- Up/Down “CH” buttons: Same function as SET button
- Left/Right “VOL” buttons: Decrement (new feature) or Increment (same as INCR) button functions
- AV/TV button: Initiates Announce All Items (same as holding TALK button for longer than 2 seconds).
Reprogramming:
Remote uses one CR2032 coin battery that should last you a long time. However if battery is replaced or accidently remodeled, remote might lose its programming and will stop controlling Xronos clock. Fortunately you can reprogram it. This requires some patience and a little tricky but can be done. Here’s procedure:
1. Disable InfoDisplay (Texts scrolling) function by going to User Menu->InfoDisplay and set frequency to “Never”
2. Make sure that at least one Talk Item is on (i.e. time announcement)
3. Point remote towards face of the Xronos Clock
4. Press and hold “Mute” button on the remote.

5. At this point remote enters programming mode and will cycle between different IR codes know to it. As soon you hear clock start talking release Mute button immediately.
6. Press On/Off or Mute button again to see if remote found right code. If nothing happens you skipped the right code and you’ll need to start process again from step 3. Usually on second try you will find right code almost immediately, but if you skipped too far you’ll have to hold button for several minutes until it cycles back thru all the IR codes. I know this part can be frustrating but unfortunately it’s the only way.

RMF12B transceiver
Another optional accessory is RFM12B chip which allows Xronos clock to receive (and possibly) send data over 915Mhz (or 413Mhz) frequency from/to sensor/device that’s also has RFM12B chip. As of this writing we do not have any accessories for sale that will work with RFM12B chip, but you are welcome to make your own. Out of the box Xronos clock supports remote temperature and humidity data. If you want to build your own sensor use Arduino code provided on our website (xronosclock.com).
If you are maker possibilities are endless. Here are few ideas:
- You can connect your own RFM12B based transmitter to computer and with right code you can send RSS feeds, emails, tweets, etc. to the Xronos clock (of course some coding will be required).
- Make several Xronos clocks talk to each other, or synchronize from external time source (i.e. GPS reciever).
- Build mailbox sensor and make your Xronos clock display alert when snail mail is reiceved.
We hope to release outdoor battery powered sensor some time in 1st half of 2014.
Things to keep in mind. You must reset/unplug your clock if you turn RF Setting on or off.
When RF is enabled, RF indicator (in top right corner) will be showing status of received data. If no data received after clock reset it will be RED. When receiving data it will turn green briefly and when go off. If no data received for over 30 minutes it will become RED again.
Keep in mind that no radio data can be received when clock is playing audio (i.e. alarm sounds, time is announced, etc.)

Complete Menu System Reference

Set Alarm 1: Controls 1st alarm

- On/Off : I’ll let you guess what it does :)
- Alarm Frequency:
- Custom: Let’s user choose any combination of days when alarm will sound ■ Mon: Y/N
■ Tue: Y/N
■ ....
■ Sun: Y/N
■ Exit: This option will exit day selection and goes to following time
- Daily: Alarm will sound every day
- Weekdays: Alarm will sound on usual workdays, i.e. Mon-Fri
- Alarm Hours/Minutes: Let’s you select time when alarm will sound
- Tone: Select Tone/Melody that’s played back as alarm. Tones 1-5 are escalating, 6-10 are played at full volume

Set Alarm 2 : Controls 2nd Alarm (Same options as above)

Time/Date: Sets current Time/Date

- Hours/Minutes
- Day/Month/Year (maximum Year allowed 2040, after which it goes back to 2013)

Sys Setup: Sets global clock settings

- Mode: Choose 12 hour (AM/PM) or 24 hour clock mode
- Brightness: Select LED display brightness from Night (lowest) to Max (brightest)
- Color: Sets Clock Color. Choices are Green, Red or Orange
- Font: Select Font of Main (big) clock display.
- Temp: Chooses temperature units. F = Fahrenheit = Celsius
- Sound Vol: Volume of System sounds and announcements. Does not affect alarm volume.
- Startup: Turns on/off startup sequence when clock is reset or powered on
- RF Sensor: Turns on/off optional RFM12B sensor. Reboot required.
Warning: Do not turn on if you don’t have RFM12B chip installed!
Warning: You must reboot/reset clocks if you turn this feature on or off.
- IR Receiver: Turns on/off optional infrared remote accessory. Reboot required.

User Menu: Sets User preferences

- Info Display – Controls what and is shown in scrolling text line and how frequently.
- Show Every: Controls frequency of Info Display, disables it and lets you select which item to show.
- Displ Date: Y/N Option to display date
- Displ InTemp: Y/N Option to display temperature form internal sensor
- Displ Extemp: Y/N Option to display temperature from optional external sensor. This item will not show up if RF sensor is turned off.
- Displ Alarm: Y/N Option to display alarm settings
- Displ RFStat: Y/N Option to display last time data from option external RF sensor was received. This item will not show up if RF sensor is turned off.
- Displ Humid: Y/N Option to display humidity data from optional external sensor. This item will not show up if RF sensor is turned off.
- Exit
- Talk Items
- Say Time: Y/N Option to announce Time when “TALK” button is pressed or held
- Say Date: Y/N Option to announce Date when “TALK” button is pressed or held
- Say InTemp: Y/N Option to announce Temperature from internal sensor when “TALK” button is pressed or held
- Say ExTemp: Y/N Option to announce temperature from option external sensor when “TALK” button is pressed or held. This item will not show up if RF sensor is turned off.
- Say Humid: Y/N Option to announce humidity data from option external sensor when “TALK” button is pressed or held. This item will not show up if RF sensor is turned off.
- Say Alrm: Y/N Option to announce Alarm settings when “TALK” button is pressed or held
- Exit
- Temp Offs: Sets negative offset to current temperature from internal sensor.

Maintenance and Hacking

Depending on preference your Xronos Alarm Clock should be wiped from time to time to remove accumulated dust. Or not. Other than this, you might have to occasionally change internal clock battery in case you notice clock loses time if there was power interruption. Xronos takes generic CR2032 coin type 3V battery.

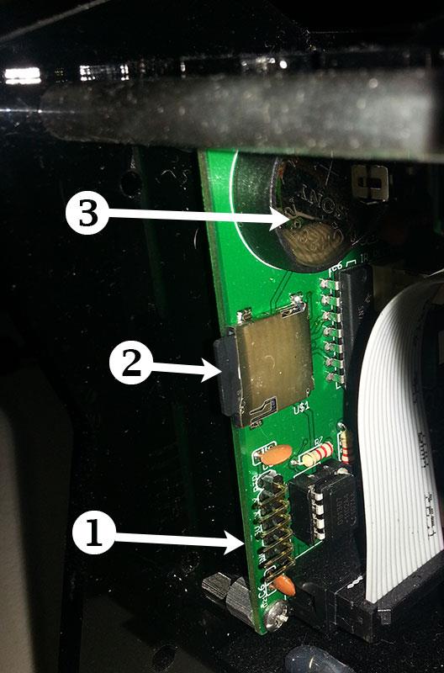
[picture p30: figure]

1 – FTDI Pins (for updating Firmware and communicating with clock) 2 – microSD Card (for changing audio data or Alarm tones)
2 – CR2032 Battery

Battery replacing procedure

To replace battery you will need a small Philips head screwdriver to open maintenance door on the left side of the clock. Here are steps to open maintenance door:
1 Unplug your Xronos Clock.
2 Looking at the front of the clock maintenance door is on the left of the clock (opposite from speaker side) held by 3 small screws (as shown on the picture above)
3 Gently remove screw that holds door from the back of the clock (1).
4 Unscrew two screws (2,3) on the bottom of the maintenance door. These are a little shorter than the screw you removed from the back. Try not to mix them.
5 Door should now come off easily, it’s only held by the tab on the bottom.

6 You should see internal battery. Using small flat screwdriver gently push metal retainer clip outward until it releases battery.

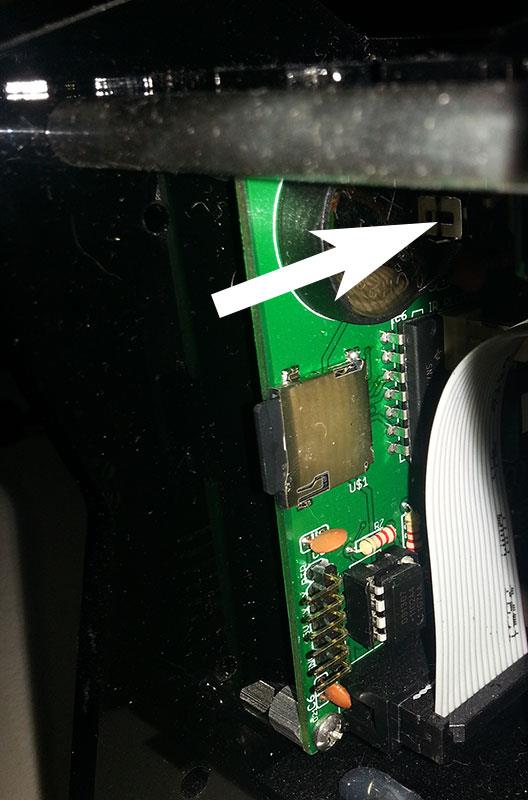
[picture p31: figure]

7 Replace with fresh battery. Insert it from plastic end opposite to metal clip first, and then press down until retainer clip clicks holding it in place.

Upgrading Firmware

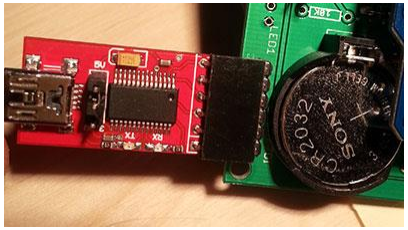
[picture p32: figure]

Removing maintenance door will also allow you access to the FTDI programming interface. You will need a 5V USB FTDI adapter board or cable (you can get one on Sparkfun or eBay). Make sure you unplug external power first. FTDI will provide power to the clock from your computer via USB. Please take care of plugging FTDI adapter correctly. Usually it means facing up (as show on the picture). Just look and match writing next to the pins (i.e. DTR on the far left, Ground on the far right).

There are basically two way to upgrade firmware, a simplified and advanced.

Simplified will require you to download AVRDude program, batch file and a hex file containing firmware.
For more advanced you will need Arduino IDE environment, required libraries and hardware files for Sanguino bootloader.

Whichever way you prefer you will still need to get FTDI adapter and install drivers for it! Firwmare is available at: http://www.xronosclock.com/ (go to Support and then to Technical Data and Downloads)

Simplified upgrade procedure:

1 Download avr.zip and extract it to your hard drive (i.e. to c:\xronos)
2 Also download update_xronos.bat file and latest HEX file with firmware. Copy both somewhere (i.e. c:\xronos)
3 Plug in USB cable from your computer to FTDI adapter and connect FTDI adapter into Xronos clock. Provided you installed drivers, your computer will acquire a COM port. 4 Take a note of the COM Port number by going Device Manger (via Control Panel -> system or right clicking on “Computer” icon on your desktop). Under Ports you will see USB Serial Port. Note it’s COM number (i.e. COM3)
5. Edit update_xronos.bat script (i.e. in Notepad)
Find two lines that specify path to AVR that you extracted in step 1: SET AVRPath="C:\Xronos\avr\bin\avrdude.exe"
SET AVRConfig="C:\Xronos\avr\etc\avrdude.conf"
And change to your actual file location
6. Open command prompt, navigate to the folder where you firmware scripts and run “start_here.bat”
7. You will be prompted for COM port, so put number you got from step 4.
8. If everything goes fine, you will see update progress and screen will turn green at successful upload.

Advanced upgrade:

1 Install latest Arduino IDE
2 Download Sanguino or Mighty 1284p hardware files and copy to your projects_home\hardware folder
3 Download and install libraries:
a Time
b DS1307RTC
c WaveHC (modified to work with Xronos Clock PCB)

d Dallas Temperature
e OneWire
f IR REmote
4 Download source code
5 Open in Arduino IDE, compile and upload to Xronos Clock

Disassembly/Reassembly

If you want to modify hardware or add optional RFM12B chip and/or IR receiver you will need to open enclosure
Warning: Please be very careful with enclosure, as acrylic tabs can be broken off easily. Never force your way, go slowly. If someone doesn’t go in, see if you have a wire in a way.
- Put soft cloth on a table so you don’t scratch clock’s face.
- Remove small screw holding maintenance door from the back
- Remove big Acorn shaped nuts from the front of the clock and remove long screws. While removing them hold back and front of the clock with your hand so it doesn’t separate.
- Lift off face plate and front panel gently. It’s attached to the mainboard with ribbon cable and IR receiver cable (if you have one installed).
- Unplug both from main board and put front panel aside. If you need to remove LED display, simply unscrew 4 screws holding it, but remember which was it was oriented.
- Main board and power supply both attached to the back panel, but power supply also attached to the side panel via power jack.
- Unscrew 4 screws holding side panels to the bottom panel.
- Nothing is attached to the maintenance door (left) panel so you can just take it out.
- Right panel is attached via speaker cable to main board and via power cable to power supply.
- You can lift off remaining panels once you unplug all cables (i.e. button cable, light sensor cable and speaker cable).
- At this point you should be able to access and remove main board easily, just unplug power cable that’s attached to the power supply and 3 wire temperature sensor cable that goes under the board to the temperature sensor glued to the back panel.
- Buttons cannot be removed without first disordering/cutting wires. If you need to replace a button (for example you want different color), carefully unsolder it, press tabs to remove, insert your own button and solder it back.

Reassembly:
- Attach Main board and power supply to the back panel. Plug in power and temperature sensor wires.
- Attach right “speaker” panel to the bottom panel with two 1/2” 4-40 screws. Leave screws slightly loose at this point! Joint will be moving slightly for easier insertion.
- Insert right and bottom panels into bottom panel gently.
- To attach top (button) panel you will need to lift right “speaker” panel slightly to match it’s tabs and insert all of them into back panel.
- Plug in all the wires (buttons, light sensor and speaker)
- Plug in LED display ribbon cable
- While making sure that no wires get caught gently lower front panel and match all tabs. If you have faceplate attached, remove it (it’s not screwed to anything) so you can see where tabs go.
- Check that all parts are fitted nicely, place faceplate on front panel and start threading long screws from the bottom until they go thru.
- Screw acorn nuts onto them from the front. Do not tighten yet.
- Alight and attach left “maintenance” door and secure it with 3 screws (2 x ½” 4-40 from side and one 9/16” 4-40 from back)
- Tighten acorn nuts with hand and also tighten 2 half inch 4-40 screws holding speaker panel. Do not over tighten them! You can break acrylic!

Note on Power Supply
Power supply that comes with clock is designed to work in USA only.
I highly recommend using Power Supply that came with the clock because clock has been intensely tested with it and I went thru many different kinds until current one was chosen.
If you must use different one (i.e. your country uses different plug) please make sure that:
1. It has correct polarity: Tip is Positive and Outer jacket is negative. This is the most important thing, as wrong polarity will damage clock!
2. Supplied voltage is at least 6 Volts DC and not more than 24 V
3. DC plug is security stays in the socket! If you touch the wire and clock reboots, it mean that plug is no good. Bad plug can cause reversible damage to the clock. I’ve seen contents of the flash being erased due to the bad plug (although on extremely rare occasion). While this won’t permanently brick your clock, you’ll have to reprogram it if it happens.

Troubleshooting
Symptom | Possible Solution
User settings (such as Color, or Mode are being reset) | Check if Power Supply is connected security and nothing pulling the wire
Time and/or date is not kept correctly (i.e. it’s really off by hours or days) | Make sure you are using Power Supply with output of 6V or more (up to 24)
Time/Date lost after power loss or reset | Replace internal coin battery
Nothing show on the screen, no signs of life even when pressing MENU button | Try resetting clock by pressing Reset button. Unplug Power supply form the clock. Wait 10 seconds and plug it back in. Open maintenance door and see if any wires are loose, check that microSD card is fully in. (Clock won’t work without microSD or if files are missing) If you have FTDI adapter/cable see if you can get any serial output that will tell you anything meaningful (set baud rate to 115200). Try uploading latest firmware or sent clock back to me for repair/reprogramming.

Remember 99% of issues will result from bad or insecurely plugged power supply. Never use clock if power cable is moving around or stretched. Always plug and unplug it in single quick motion. Don’t pull on the cable.

Warranty
I will fix or replace fully assembled Xronos clock in the period of ONE YEAR since date of sale if issue is due to the manufacturing defect. Because this is open source and hackable device, I cannot be held responsible if you damage it, so warranty will be voided if you modified the clock. Also warranty doesn’t apply to KIT version of the clock.
Having said that I’m still willing to offer reasonable help and repair on case by case basis.

Disclaimer
I will not be held responsible for any issues resulted by Xronos Alarm Clock or from it’s usage. Use at your own risk.

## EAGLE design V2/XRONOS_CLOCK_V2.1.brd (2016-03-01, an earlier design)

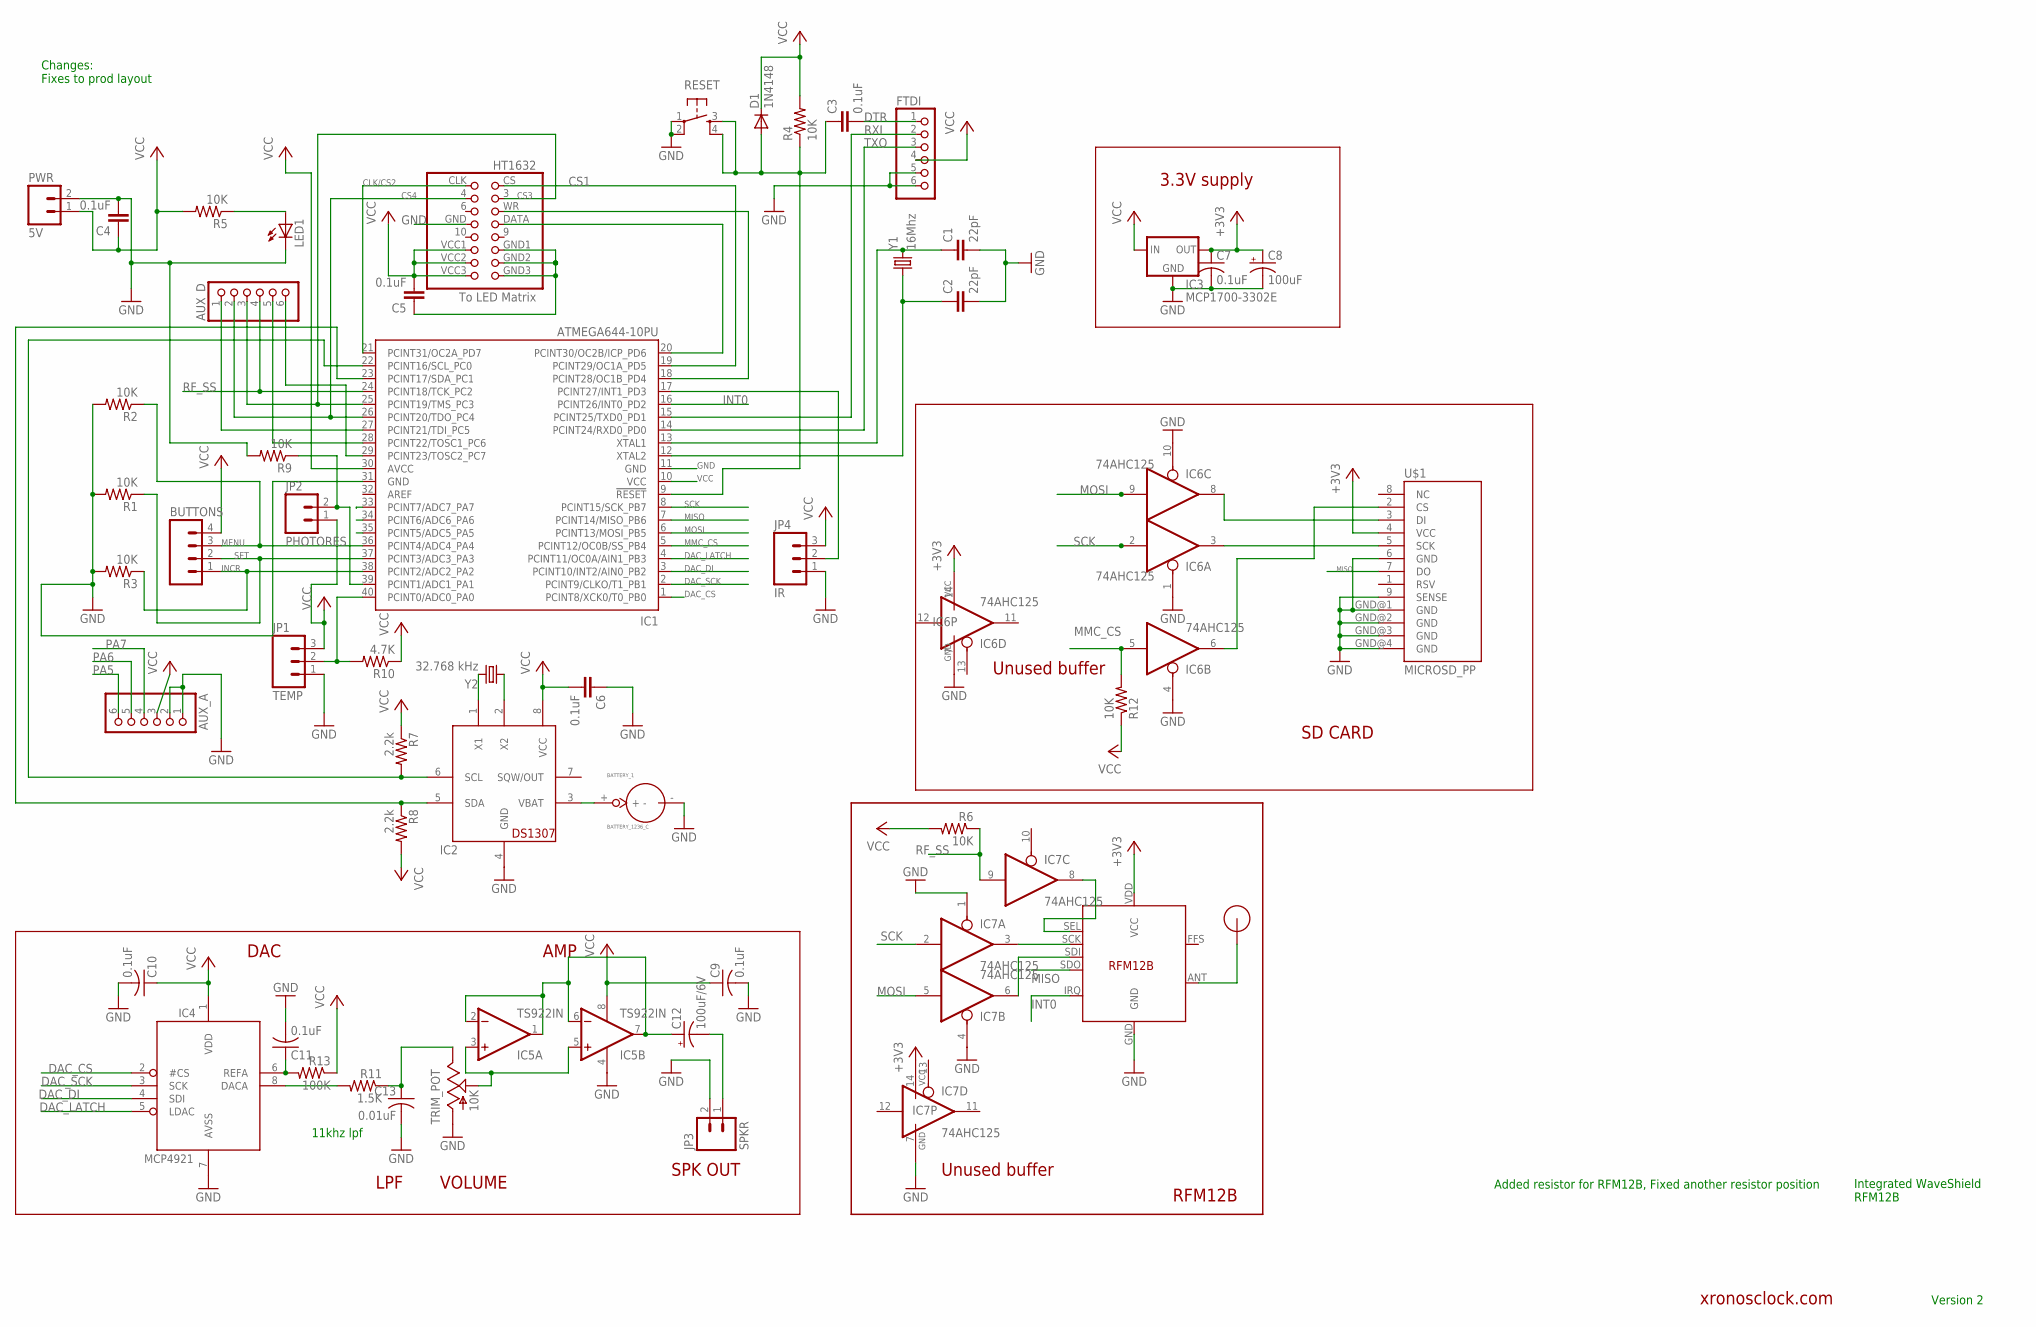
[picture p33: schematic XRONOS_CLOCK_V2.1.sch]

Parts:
AUX_A: PINHD-1X6; 1X06
AUX_D: PINHD-1X6; 1X06
BATTERY_1: BATTERY_1236_C
BUTTONS: M04POLAR; MOLEX-1X4
C1, C2: 22pF; C025-024X044
C3, C4, C5, C6: 0.1uF; C025-024X044
C7, C9, C10, C11: 0.1uF; C025-025X050
C8: 100uF; E2,5-5
C12: 100uF/6V; E2,5-5
C13: 0.01uF; C025-025X050
D1: 1N4148; DO35-7
FTDI: PINHD-1X6; 1X06
HT1632: To LED Matrix; IDC2X08
IC1: ATMEGA644-10PU; DIL40
IC2: DS1307; DIL08
IC3: MCP1700-3302E; TO92
IC4: MCP4921; DIL08
IC5: TS922IN; DIL08
IC6: 74AHC125; DIL14-LARDO
IC7: 74AHC125; DIL14
JP1: TEMP; MOLEX-1X3
JP2: PHOTORES; MOLEX-1X2
JP3: SPKR; MOLEX-1X2
JP4: IR; MOLEX-1X3_LOCK
LED1: LED-3MM-NO_SILK; LED3MM-NS
PWR: 5V; MOLEX-1X2
R1, R2, R3, R4, R5, R9: 10K; AXIAL-0.3EZ
R6, R12: 10K; AXIAL-0.3
R7, R8: 2.2k; AXIAL-0.3EZ
R10: 4.7K; AXIAL-0.3EZ
R11: 1.5K; AXIAL-0.3
R13: 100K; AXIAL-0.3
RESET: TAC_SWITCHPTH; TACTILE-PTH
TRIM_POT: 10K; B25P
U$1: MICROSD_PP
U$2: RFM12B
U$3: RFM12B_ANTENNA; RFM12B-ANTENNA
Y1: 16Mhz; HC49US
Y2: 32.768 kHz; TC26HEZ

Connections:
+3V3: C7.1, C8.+, IC3.3 (OUT), IC6.14 (VCC), IC7.14 (VCC), U$1.4 (VCC), U$2.VDD (VCC)
ADJ: IC1.40 (PCINT0/ADC0_PA0), JP1.2, R10.P$2 (2)
CLK/CS2: HT1632.CLK (2), IC1.21 (PCINT31/OC2A_PD7)
CS1: HT1632.CS (1), IC1.19 (PCINT29/OC1A_PD5)
CS3: AUX_D.3, HT1632.3, IC1.25 (PCINT19/TMS_PC3)
CS4: AUX_D.2, HT1632.4, IC1.26 (PCINT20/TDO_PC4)
DAC_CS: IC1.1 (PCINT8/XCK0/T0_PB0), IC4.2 (#CS)
DAC_DI: IC1.3 (PCINT10/INT2/AIN0_PB2), IC4.4 (SDI)
DAC_LATCH: IC1.4 (PCINT11/OC0A/AIN1_PB3), IC4.5 (LDAC)
DAC_SCK: IC1.2 (PCINT9/CLKO/T1_PB1), IC4.3 (SCK)
DATA: HT1632.DATA (7), IC1.20 (PCINT30/OC2B/ICP_PD6)
DTR: C3.2, FTDI.1
GND: AUX_A.1, AUX_A.2, BATTERY_1.-, C1.2, C2.2, C4.2, C6.1, C7.2, C8.-, C9.2, C10.2, C11.2, C13.2, FTDI.5, FTDI.6, HT1632.GND (8), IC1.11 (GND), IC1.31 (GND), IC2.4 (GND), IC3.1 (GND), IC4.7 (AVSS), IC5.4 (V-), IC6.1 (OE), IC6.4 (OE), IC6.7 (GND), IC6.10 (OE), IC7.1 (OE), IC7.4 (OE), IC7.7 (GND), JP1.1, JP3.2, JP4.1, LED1.K (C), PWR.2, R1.P$2 (2), R2.P$2 (2), R3.P$2 (2), R9.P$2 (2), RESET.1, RESET.2, TRIM_POT.A, U$1.6 (GND), U$1.9 (SENSE), U$1.GND@1 (GND), U$1.GND@2 (GND), U$1.GND@3 (GND), U$1.GND@4 (GND), U$2.GND
INCR: BUTTONS.1, IC1.38 (PCINT2/ADC2_PA2), R3.P$1 (1)
INT0: IC1.16 (PCINT26/INT0_PD2), U$2.IRQ
MENU: BUTTONS.3, IC1.36 (PCINT4/ADC4_PA4), R2.P$1 (1)
MISO: IC1.7 (PCINT14/MISO_PB6), U$1.7 (DO), U$2.SDO
MMC_CS: IC1.5 (PCINT12/OC0B/SS_PB4), IC6.5 (I), R12.P$2 (2)
MOSI: IC1.6 (PCINT13/MOSI_PB5), IC6.9 (I), IC7.5 (I)
unnamed: U$2.ANT, U$3.P$1
unnamed: C5.1, HT1632.GND1 (11), HT1632.GND2 (13), HT1632.GND3 (15)
unnamed: IC2.2 (X2), Y2.1
unnamed: IC2.1 (X1), Y2.2
unnamed: C1.1, IC1.13 (XTAL1), Y1.2
unnamed: BATTERY_1.+, IC2.3 (VBAT)
unnamed: IC7.8 (O), U$2.SEL
unnamed: IC1.17 (PCINT27/INT1_PD3), JP4.2
unnamed: C2.1, IC1.12 (XTAL2), Y1.1
unnamed: AUX_D.1, IC1.27 (PCINT21/TDI_PC5)
unnamed: IC1.39 (PCINT1/ADC1_PA1), JP2.2, R9.P$1 (1)
unnamed: AUX_D.5, IC1.28 (PCINT22/TOSC1_PC6)
unnamed: AUX_D.6, IC1.29 (PCINT23/TOSC2_PC7)
unnamed: IC6.8 (O), U$1.3 (DI)
unnamed: LED1.A, R5.P$1 (1)
unnamed: IC6.3 (O), U$1.5 (SCK)
unnamed: IC6.6 (O), U$1.2 (CS)
unnamed: IC4.8 (DACA), R11.P$2 (2)
unnamed: C12.-, JP3.1
unnamed: C12.+, IC5.1 (OUT), IC5.2 (-IN), IC5.6 (-IN), IC5.7 (OUT)
unnamed: C11.1, IC4.6 (REFA), R13.P$2 (2)
unnamed: IC5.3 (+IN), IC5.5 (+IN), TRIM_POT.S
unnamed: C13.1, R11.P$1 (1), TRIM_POT.E
unnamed: IC7.6 (O), U$2.SDI
unnamed: IC7.3 (O), U$2.SCK
PA5: AUX_A.6, IC1.35 (PCINT5/ADC5_PA5)
PA6: AUX_A.5, IC1.34 (PCINT6/ADC6_PA6)
PA7: AUX_A.4, IC1.33 (PCINT7/ADC7_PA7)
RESET: C3.1, D1.A, IC1.9 (!RESET), R4.P$1 (1), RESET.3, RESET.4
RF_SS: AUX_D.4, IC1.24 (PCINT18/TCK_PC2), IC7.9 (I), R6.P$1 (1)
RXI: FTDI.2, IC1.15 (PCINT25/TXD0_PD1)
SCK: IC1.8 (PCINT15/SCK_PB7), IC6.2 (I), IC7.2 (I)
SCL: IC1.23 (PCINT17/SDA_PC1), IC2.5 (SDA), R8.P$1 (1)
SDA: IC1.22 (PCINT16/SCL_PC0), IC2.6 (SCL), R7.P$2 (2)
SET: BUTTONS.2, IC1.37 (PCINT3/ADC3_PA3), R1.P$1 (1)
TXO: FTDI.3, IC1.14 (PCINT24/RXD0_PD0)
VCC: AUX_A.3, BUTTONS.4, C4.1, C5.2, C6.2, C9.1, C10.1, D1.C, FTDI.4, HT1632.VCC1 (12), HT1632.VCC2 (14), HT1632.VCC3 (16), IC1.10 (VCC), IC1.30 (AVCC), IC2.8 (VCC), IC3.2 (IN), IC4.1 (VDD), IC5.8 (V+), JP1.3, JP2.1, JP4.3, PWR.1, R4.P$2 (2), R5.P$2 (2), R6.P$2 (2), R7.P$1 (1), R8.P$2 (2), R10.P$1 (1), R12.P$1 (1), R13.P$1 (1)
WR: HT1632.WR (5), IC1.18 (PCINT28/OC1B_PD4)

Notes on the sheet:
Version 2
Changes: Fixes to prod layout
Integrated WaveShield RFM12B
11khz lpf
DAC
VOLUME
LPF
AMP
SPK OUT
SD CARD
3.3V supply
Unused buffer
RFM12B
xronosclock.com
Added resistor for RFM12B, Fixed another resistor position

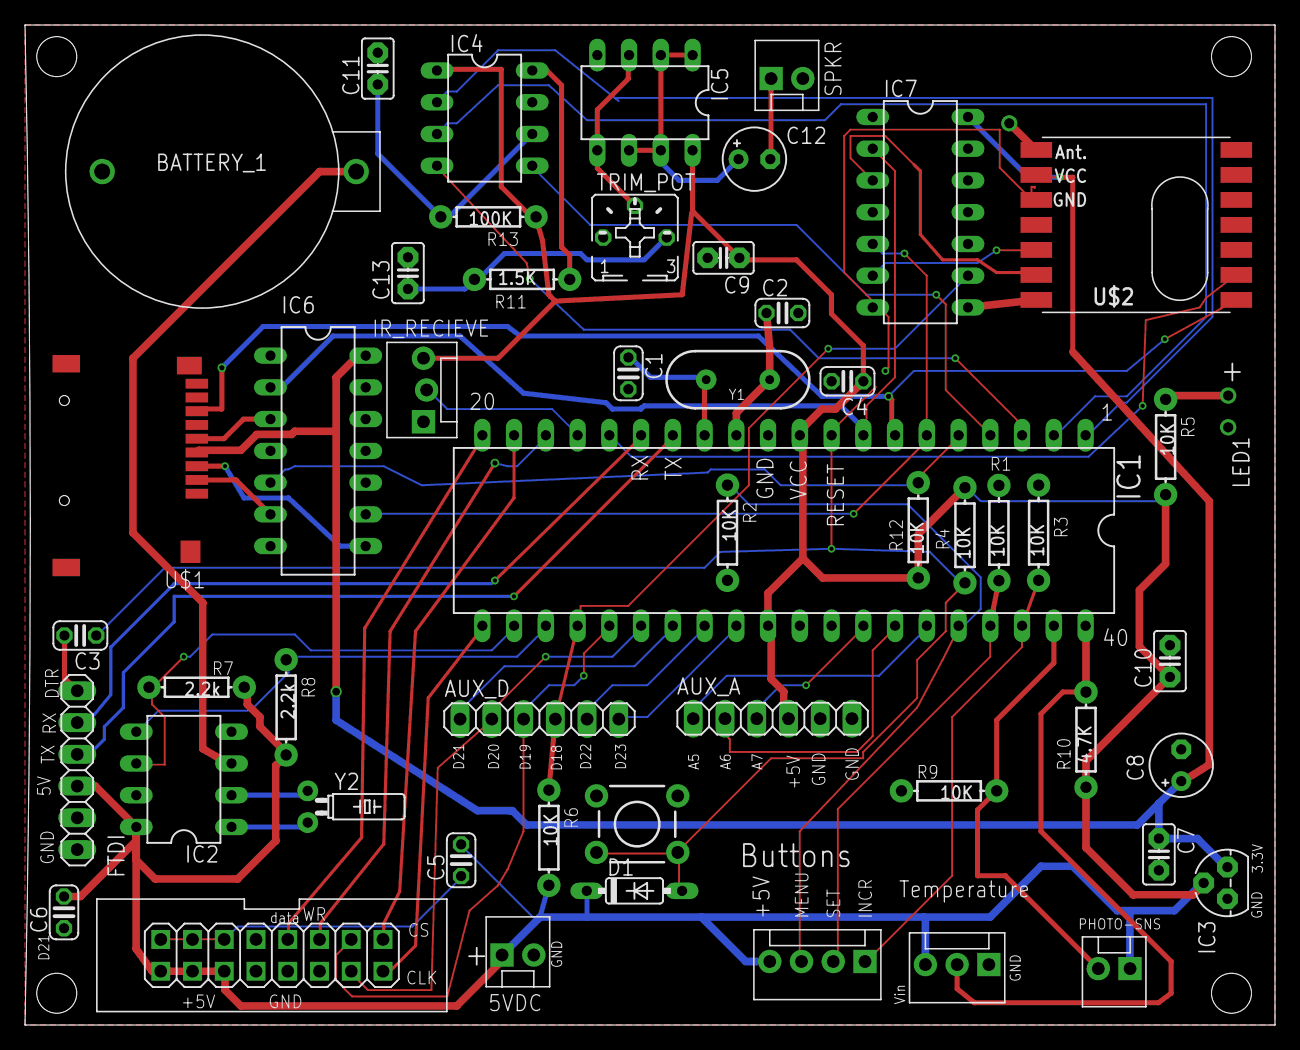
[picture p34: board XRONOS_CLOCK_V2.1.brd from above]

Board: 2 copper layers, 100.0 x 80.0 mm, 53 parts (0 on the bottom side), 57 nets.

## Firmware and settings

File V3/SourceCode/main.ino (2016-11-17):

// =======================================================================================
// ---- First time clock is powered, play startup music, show vers and say time ----
// ---------------------------------------------------------------------------------------
void startup ()
{
  if (!doStartup) return; // Startup Disabled?
  //void initEPROM();
  char welcome[15];
  //byte ver=EEPROM.read (clockVerLoc); // Read 3 digit version number
  int ver=EEPROMReadInt(clockVerLoc);
  int temp = (ver%100); //temp holder
  int ver3 = temp % 10; // Last digit
  int ver2 = (temp - ver3) / 10; // Second Digit
  ver = (ver - ver2) / 100; // First digitf
  playfile("STARTUP1.WAV");
  showText(0,0,"Welcome",3,GREEN);
  snprintf(welcome, sizeof(welcome),"Firmware:V%d.%d%d",ver,ver2,ver3); 
  scrolltextsizexcolor(8,welcome,RED,15);
  cls();
  showBigTime(clockColor);
}

// =======================================================================================
// ---- Initializes EEPROM for new Chip. run only first time ----
// ---------------------------------------------------------------------------------------
void initEPROM()
{
  putstring_nl ("Writing Initial settings to EEPROM!!!");
 for (byte i=0;i<2;i++) {
    EEPROM.write (alarmHHLoc[i],0);  
    delay (50);
    EEPROM.write (alarmMMLoc[i],0);
    delay (50);
    EEPROM.write (alarmOnOffLoc[i],0);
    delay (50);
    EEPROM.write(alarmToneLoc[i],1); // Write Alarm Tone number
    delay (50);
 }
  EEPROM.write (mode24HRLoc,false); // Write time mode (12/24 hours)
  delay (50);
  EEPROM.write (brightLoc,3); // Write Brightness setting
  delay (50);
  EEPROM.write (clockColorLoc,GREEN); // Write Clock Color
  delay (50);
  //EEPROM.write (clockVerLoc,firmware_ver); 
  EEPROMWriteInt(clockVerLoc,firmware_ver);
  delay (50);
  EEPROM.write(clockFontLoc,1); // Write Alarm Tone number
  delay (50);
  EEPROM.write (sFXLoc,1); // Write Menu SFX on/off
  delay (50);
  EEPROM.write (tempUnitLoc,true);// Write Temperature units
  delay (50);
  EEPROM.write (sndVolLoc,0);// Write Sound Volume
  delay (50);
  EEPROM.write(infoFreqLoc,2); // Write infodisplay freq options
  delay (50);
  EEPROM.write(sayOptionsLoc,255); // Write Say options
  delay (50);
  EEPROM.write(doStartupLoc,true); // Write Startup option
  delay (50);
  EEPROM.write(tmpOffsetLoc,2); // Write Temperature Offset
  delay (50);
  EEPROM.write(infoOptionsLoc,2); // Write InfoDisplay options
  delay (50);
  EEPROM.write(radioOnLoc,false); // Disable RFM by default during INIT
  delay (50);
  EEPROM.write(IROnLoc,true); // Disable IR by default during INIT
  delay (50);
  EEPROM.write(RF_FreqLoc,0); // Write Frequency
  delay (50);
  EEPROM.write(RF_NodeLoc,NODEID); // Write 
  delay (50);
  EEPROM.write(RF_GatewayLoc,GATEWAYID); // Write 
  delay (50);
  EEPROM.write(RF_NetworkLoc,NETWORKID); // Write 
  delay (50);
  EEPROM.write(RF_SensorLoc,SENSORID); // Write 
  delay (50);
  EEPROM.write(RF_EncryptLoc,true); // Write
  delay (25);
  EEPROM.write(currTZLoc,0); // Write Current Timezone index
  delay (25);
 // Write TimeZones
  usEastern.writeRules(ESTLoc);
  usCentral.writeRules(CSTLoc);
  usMountain.writeRules(MSTLoc);
  usArizona.writeRules(AZSTLoc);
  usPacific.writeRules(PSTLoc);
  usAlaska.writeRules(AKSTLoc);
  usHawaii.writeRules(HSTLoc);
  Universal.writeRules(UTCLoc);
}

// Display divider colon :
void showDivider(byte color){
  int x=0; //offset
  if(time12hr) x=2; // Offset divider by 2 dots left for 12 hr mode
  if (clockFont<3) plot (15-x,5,color);
  plot (16-x,5,color);
  if (clockFont<3) plot (15-x,6,color);
  plot (16-x,6,color);
  if (clockFont<3) plot (15-x,9,color);
  plot (16-x,9,color);
  if (clockFont<3) plot (15-x,10,color);
  plot (16-x,10,color);
}

// =======================================================================================
// ---- Info display ----
// By: LensDigital
// ---------------------------------------------------------------------------------------
void infoDisplay() {
  if (isInMenu) return; // Do not show when in menu
  if (isInQMenu) return; // Do not show when in quick menu
  if (infoFreq == 0) return; // User choose to never show this screen
  if (! ((infoOptions & IO_Date) || (infoOptions & IO_InTemp) || (infoOptions & IO_OutTemp) || (infoOptions & IO_Alarms) || (infoOptions & IO_RFStat) || (infoOptions & IO_OutHum)) ) return; // All display options disabled
  if (soundAlarm[0] || soundAlarm[1]) return; // Do not show if Alarm is playing
  
  // Check if it's time to Show Info display 
  if ( (minute()%10)%infoFreq == 0 && ( second()==5) )  { // Show date and temp every XX minutes and 5 seconds
    char myString[44];
    //if ( (minute()%10)==0) return; // Prevents showing during 0 digit time
    cls();
    showSmTime(0,clockColor); // Show Time on top
    if (infoOptions & IO_Date) // Option Enabled?
      if (!showDate(clockColor)) return; // Scroll Date. Exit if scroll was interrupted by button press
    if (infoOptions & IO_InTemp) // Option Enabled?
      if (!showTemp(clockColor,false,true)) return; // Scroll Inside Temp. Exit if scroll was interrupted by button press
    #if not defined XRONOS2
      if (infoOptions & IO_InHum) // Option Enabled?
        if (!showHumidity(clockColor,0,false)) return; // Scroll Inside Temp. Exit if scroll was interrupted by button press
    #endif
    cls(); 
    if (isRadioPresent) {
        if (infoOptions & IO_OutTemp) {// Option Enabled?
          if (!showTemp(clockColor,false,false)) return; // Scroll Outside Temp. Exit if scroll was interrupted by button press
         cls();
        }
        if (infoOptions & IO_OutHum) {// Humidity Option Enabled?
        if (!showHumidity(clockColor,1,false)) return; //Scroll Outside Humidity. Exit if scroll was interrupted by button press
        cls ();
        }
    }
    if (infoOptions & IO_Alarms) {// Option Enabled?
      if (!alarmInfo(0)) return; //Show info for alarm 1. Exit if scroll was interrupted by button press
      cls ();
      if (!alarmInfo(1)) return; //Show info for alarm 2. Exit if scroll was interrupted by button press
      cls();
    }
    if (isRadioPresent) 
      if (infoOptions & IO_RFStat) {// Option Enabled?
        showSensorData();
         cls ();
      }
  }
}

// =======================================================================================
// ---- shows alarm information For Info display ----
// Returns False if scrolling function was interrupted by buttons
// By: LensDigital
// ---------------------------------------------------------------------------------------
boolean alarmInfo(byte alrmNum){
  if ( ! (alarmon[alrmNum] & ALRM_TGL) ) return true; //  Alarm is off
     char myString[54]; // String to keep Alarm msg
     char wkdays[28]; //Days of week
     showSmTime(0,clockColor); // Show time on top
     if ( snoozeTime[alrmNum]!=10 ) { // Are we snoozing?
       snprintf(myString,sizeof(myString), "Alarm%d on! Snoozing...Z Z z z z z...",alrmNum+1);
       return scrolltextsizexcolor(8,myString,RED,5);
     }
     else { // Alarm is on but not snoozing
       if (alarmon[alrmNum] == DAILY) {  // Daily Alarm
         if(time12hr) { // It's 12 hour mode
           if (hoursMode(alrmHH[alrmNum]) )  // Check if it's AM
             snprintf(myString,sizeof(myString), "Alarm %d is set Daily at %d:%02d AM",alrmNum+1,myhours,alrmMM[alrmNum]); 
           else // It's PM
             snprintf(myString,sizeof(myString), "Alarm %d is set Daily at %d:%02d PM",alrmNum+1,myhours,alrmMM[alrmNum]); 
         }
         else // It's 24 hour mode
           snprintf(myString,sizeof(myString), "Alarm %d is set Daily at %02d:%02d",alrmNum+1,alrmHH[alrmNum],alrmMM[alrmNum]); 
       }
       else if (alarmon[alrmNum] == WEEKDAY) {  // It's WeekDay alarm
         if(time12hr) { // It's 12 hour mode
           myhours = alrmHH[alrmNum];
           if (myhours == 0) 
             myhours=12; // It's Midnight
           else if (myhours >12) myhours=myhours-12;
           if (alrmHH[alrmNum]<12) // Show AM
             snprintf(myString,sizeof(myString), "Alarm %d is set M-F at %d:%02d AM",alrmNum+1,myhours,alrmMM[alrmNum]); 
           else 
             snprintf(myString,sizeof(myString), "Alarm %d is set M-F at %d:%02d PM",alrmNum+1,myhours,alrmMM[alrmNum]); 
         }
         else // It's 24 hour mode
         snprintf(myString,sizeof(myString), "Alarm %d is set M-F at %02d:%02d",alrmNum+1,alrmHH[alrmNum],alrmMM[alrmNum]); 
       }
       else {  // It's Custom alarm
          // Make custom string containing each weekday that alarm is set too
         strcpy (wkdays,"");
         if (alarmon[alrmNum] & MON)  strcat (wkdays, "Mon ");
         if (alarmon[alrmNum] & TUE)  strcat (wkdays, "Tue ");
         if (alarmon[alrmNum] & WED)  strcat (wkdays, "Wed ");
         if (alarmon[alrmNum] & THU)  strcat (wkdays, "Thu ");
         if (alarmon[alrmNum] & FRI)  strcat (wkdays, "Fri ");
         if (alarmon[alrmNum] & SAT)  strcat (wkdays, "Sat ");
         if (alarmon[alrmNum] & SUN)  strcat (wkdays, "Sun ");
           
          if(time12hr) { // It's 12 hour mode
           myhours = alrmHH[alrmNum];
           if (myhours == 0) 
             myhours=12; // It's Midnight
           else if (myhours >12) myhours=myhours-12;
           if (alrmHH[alrmNum]<12) // Show AM
             snprintf(myString,sizeof(myString), "Alarm%d is set to %d:%02d AM %s",alrmNum+1,myhours,alrmMM[alrmNum],wkdays); 
           else 
             snprintf(myString,sizeof(myString), "Alarm%d is set to %d:%02d PM %s",alrmNum+1,myhours,alrmMM[alrmNum],wkdays); 
         }
         else // It's 24 hour mode
         snprintf(myString,sizeof(myString), "Alarm%d is set to %02d:%02d %s",alrmNum+1,alrmHH[alrmNum],alrmMM[alrmNum],wkdays); 
       }
     return scrolltextsizexcolor(8,myString,clockColor,5);
     }
     
}


// =======================================================================================
// ---- Says current time ----
// By: LensDigital
// ---------------------------------------------------------------------------------------
void sayTime(){
     playcomplete("TIME_IS.WAV");
     char myString[9];
     myhours=hour(LOCAL_TZ); // Converter from UTC to local
     if(time12hr) { // == 12 Hour Mode ====
       snprintf(myString,sizeof(myString), "%d.WAV",hourFormat12(LOCAL_TZ ) ); // Make Hours string
       playcomplete(myString); // Play Hours
     }
     else // == 24 Hour Mode ====
       if (myhours > 20) { // Make complex 2 digit sound
         playcomplete("20.WAV"); // Play Hours 1st digit
         snprintf(myString,sizeof(myString), "%d.WAV",myhours%10); // Make Hours 2nd digit string
         playcomplete(myString); // Play Hours 2nd digit
       }
       else { // Simple
         snprintf(myString,sizeof(myString), "%d.WAV",myhours); // Make Hours string
         playcomplete(myString); // Play Hours
       }
     if (minute()<20) {
       if (minute()==0) { // We are at hh:00
         if (!time12hr)  playcomplete("100.WAV");  // only say "hundred" if in 24 hour mode (wbp)
       } 
       else {
         if (( (minute()/10)%10) == 0) playcomplete ("OH.WAV"); // If first digit of minute is 0, say "oh"
         snprintf(myString,sizeof(myString), "%d.WAV",minute()); // Make Minutes string
         playcomplete(myString);
         }
       }
     else { // Make complex 2 digit sound
       minutes=(minute()/10)%10;
       switch (minutes){ // Create 1st digit sound
         case 2:
           playcomplete ("20.WAV");
           break;
         case 3:
           playcomplete ("30.WAV");
           break;
         case 4:
           playcomplete ("40.WAV");
           break;
         case 5:
           playcomplete ("50.WAV");
           break;
       }
       if ((minute()%10)!=0) { // Don't say if last digit is 0
         snprintf(myString,sizeof(myString), "%d.WAV",minute()%10); // Make 2nd digit
         playcomplete(myString); // Play 
       }
     }
     // If needed say AM or PM
     if(time12hr) { // == 12 Hour Mode ====
       if (isAM(LOCAL_TZ))  playcomplete("AM.WAV");
       else playcomplete("PM.WAV");
     }
   
}

// =======================================================================================
// ---- Says current time ----
// By: LensDigital
// ---------------------------------------------------------------------------------------
void sayAlarm(byte alrmNum){
  char myString[9];  
   playcomplete("ALARM.WAV");
  snprintf(myString,sizeof(myString), "%d.WAV",alrmNum+1); // Make and say alarm number
  playcomplete(myString);
  playcomplete("IS.WAV");
  playcomplete("SET.WAV");
  playcomplete("2.WAV");
  
  if(time12hr) { // It's 12 hour mode
           myhours = alrmHH[alrmNum];
           if (myhours == 0) 
             myhours=12; // It's Midnight
           else if (myhours >12) myhours=myhours-12;
           snprintf(myString,sizeof(myString), "%d.WAV",myhours); // Make hours filename
           playcomplete(myString); // Play Hours
   }
     else // == 24 Hour Mode ====
       if (alrmHH[alrmNum] > 20) { // Make complex 2 digit sound
         playcomplete("20.WAV"); // Play Hours 1st digit
         snprintf(myString,sizeof(myString), "%d.WAV",alrmHH[alrmNum]%10); // Make Hours 2nd digit string
         playcomplete(myString); // Play Hours 2nd digit
       }
       else { // Simple
         snprintf(myString,sizeof(myString), "%d.WAV",alrmHH[alrmNum]); // Make Hours string
         playcomplete(myString); // Play Hours
       }
     if (alrmMM[alrmNum]<20) {
       if (alrmMM[alrmNum]==0) { playcomplete("100.WAV"); } // We are at hh:00
       else {
         if (( (alrmMM[alrmNum]/10)%10) == 0) playcomplete ("OH.WAV"); // If first digit of minute is 0, say "oh"
         snprintf(myString,sizeof(myString), "%d.WAV",alrmMM[alrmNum]); // Make Minutes string
         playcomplete(myString);
         }
       }
     else { // Make complex 2 digit sound
       minutes=(alrmMM[alrmNum]/10)%10;
       switch (minutes){ // Create 1st digit sound
         case 2:
           playcomplete ("20.WAV");
           break;
         case 3:
           playcomplete ("30.WAV");
           break;
         case 4:
           playcomplete ("40.WAV");
           break;
         case 5:
           playcomplete ("50.WAV");
           break;
       }
       if ((alrmMM[alrmNum]%10)!=0) { // Don't say if last digit is 0
         snprintf(myString,sizeof(myString), "%d.WAV",alrmMM[alrmNum]%10); // Make 2nd digit
         playcomplete(myString); // Play 
       }
     }
     // If needed say AM or PM
     if(time12hr) { // == 12 Hour Mode ====
       if (alrmHH[alrmNum]<12)  playcomplete("AM.WAV");
       else playcomplete("PM.WAV");
     }
     if (alarmon[alrmNum] == DAILY) playcomplete("DAILY.WAV");// Daily Alarm
     else if (alarmon[alrmNum] == WEEKDAY) playcomplete("wkdays.WAV");// Workday Alarm
     else { // Custom ALarm
       playcomplete("EVERY.WAV");
       if (alarmon[alrmNum] & MON) playcomplete("MON.WAV");
       if (alarmon[alrmNum] & TUE) playcomplete("TUE.WAV");
       if (alarmon[alrmNum] & WED) playcomplete("WED.WAV");
       if (alarmon[alrmNum] & THU) playcomplete("THU.WAV");
       if (alarmon[alrmNum] & FRI) playcomplete("FRI.WAV");
       if (alarmon[alrmNum] & SAT) playcomplete("SAT.WAV");
       if (alarmon[alrmNum] & SUN) playcomplete("SUN.WAV");
     }
     
}

// =======================================================================================
// ---- Announce Internal Temperature ----
// By: LensDigital
// ---------------------------------------------------------------------------------------
void sayTemp(int temp, boolean location){
  /*
  if (temp > 100 || temp < -50) {
    playcomplete ("ERR1.WAV");
    return;
  } */
  int unsignedTemp=temp; // Will remove negative sign for vocal processing.
  char myString[8];
  playcomplete("TEMP.WAV");
  if (location) playcomplete("INSIDE.WAV");
  else playcomplete("OUTSIDE.WAV");
  playcomplete("IS.WAV");
 
  if (temp<0) { // Handle Negative temperatures
    playcomplete("MINUS.WAV");
    unsignedTemp=unsignedTemp*-1;// Converts negative to positive
  }
  if (temp<20) {
    snprintf(myString,sizeof(myString), "%d.WAV",unsignedTemp); // Teen and single digits
    playcomplete(myString);
  }
  else { // It's over 20, so make 2 digit phrase
    snprintf(myString,sizeof(myString), "%d0.WAV",(unsignedTemp/10)%10); // first digit
    playcomplete(myString);
    if ((temp%10)!=0) {
      snprintf(myString,sizeof(myString), "%d.WAV",unsignedTemp%10); // first digit
      playcomplete(myString);
    }
  }
  playcomplete("DEGREES.WAV");
  if (tempUnit) playcomplete("fahrenh.WAV");
  else playcomplete("CELCIUS.WAV");
}


// =======================================================================================
// ---- Announce Current Date ----
// By: LensDigital
// ---------------------------------------------------------------------------------------
void sayDate(){
  char myString[10];
  char dayofweek[4]; // Keeps day of week
  playcomplete("TODAY.WAV");
  playcomplete("IS.WAV");
  Serial.println ("Say Date!");
  switch (weekday(LOCAL_TZ)){
    case 1: //Sunday
    strcpy(dayofweek,"SUN");
    break;
    case 2: //Mon
    strcpy(dayofweek,"MON");
    break;
    case 3: 
    strcpy(dayofweek,"TUE");
    break;
    case 4: 
    strcpy(dayofweek,"WED");
    break;
    case 5: 
    strcpy(dayofweek,"THU");
    break;
    case 6: 
    strcpy(dayofweek,"FRI");
    break;
    case 7: 
    strcpy(dayofweek,"SAT");
    break;
  }
  snprintf(myString,sizeof(myString), "%s.WAV",dayofweek); // Day of Week
  playcomplete(myString);
  snprintf(myString,sizeof(myString), "%s.WAV",monthShortStr(month(LOCAL_TZ)) ); // month
  playcomplete(myString);
  if (day(LOCAL_TZ)<20) {
      snprintf(myString,sizeof(myString), "%dST.WAV",day(LOCAL_TZ)); // Make Day String
      playcomplete(myString);
         
  }
  else { // Make complex 2 digit sound
       days=(day(LOCAL_TZ)/10)%10;
       switch (days){ // Create 1st digit sound
         case 2:
           playcomplete ("20.WAV");
           break;
         case 3:
           playcomplete ("30.WAV");
           break;
       }
       if ((day(LOCAL_TZ)%10)!=0) { // Don't say if last digit is 0
         snprintf(myString,sizeof(myString),"%dST.WAV",day(LOCAL_TZ)%10); // Make 2nd digit
         playcomplete(myString); // Play 
       }
     }
  playcomplete("2.WAV");
  playcomplete("1000.WAV");
  snprintf(myString,sizeof(myString), "%d.WAV",year(LOCAL_TZ)%100); // Make 2nd digit
  playcomplete(myString); // Play 
}


// =======================================================================================
// Display large digit (full screen) time
// By: LensDigital
// ---------------------------------------------------------------------------------------
void showBigTime(byte color){
  //if (menuItem > 3 || !okClock) return; // Date setting is in progress. Do not show clock
  if (!okClock) return; // Date setting is in progress. Do not show clock
  int blinkDotDuration =500; // How frequently dots should blink
  int blinkDigDuration = 500; // Frequencey of digit blinking during time setting
  int x=0; //offset
  if (color==4)color=random(3)+1; // Select random color
  
  // Blinker processor (used to blink divider and/or digits during time setting
  if (!isInMenu)  // If we are setting time, don't blick divider
    if ( (millis()-blinkTime > blinkDotDuration)) { // It's been over blinkDuration time
      blinkTime = millis(); // reset offset to current time
      if ( blinkColor == BLACK )  {
       
        blinkColor=color; // Inverse color of divider
      }
      else {
        blinkColor = BLACK;
        
      }
     
      //else if (!blinking) blinkColor=BLACK; // If setting time don't blink divider
    }  
  
  if (blinking){ // Setting time, so blink correct digits
    //Serial.println ("Setting time");
    blinkColor=color; // Show steady divider dots
    if ( (millis()-blinkTime > blinkDigDuration)) { // It's been over blinkDuration time
      blinkTime = millis(); // reset offset to current time
      if (isSettingHours) {
        //putstring_nl ("Setting hours");
       if ( hhColor == BLACK ) hhColor = color; // Inverse color of Hours 
       else hhColor = BLACK;
       mmColor = color; // Minutes not blinking
      }
      if (isSettingMinutes) {
        //putstring_nl ("Setting minutes");
       if ( mmColor == BLACK ) mmColor = color; // Inverse color of Minutes 
       else mmColor = BLACK;
       hhColor = color; // Hours not blinking
      }
    }
  }
  else { hhColor=color; mmColor=color;} // We are not setting time, so show digits as usual
  // --- END OF BLINK PROCESSOR
    
  // Check if we are running in 12 Hour Mode:
  if(time12hr) {
  // == BEGIN 12 Hour Mode ====
    x=2; //offset horus by 2 dots
    myhours=hourFormat12(LOCAL_TZ);
    if (isAM(LOCAL_TZ)) plot (0,1,hhColor); // Show AM Dot
    else plot (0,1,BLACK); // Hide AM Dot
    if ( (myhours/10)%10 == 0 ) showDigit(0-x,2,1,5,clockFont,BLACK); // Hide first digit 
    else showDigit(0-x,2,(myhours/10)%10,5,clockFont,hhColor);
  }
  // === END 12 Hour Mode ===
  else {
  // 24 Hour Mode
   //myhours=hour();
   myhours=hour(LOCAL_TZ); // Converter from UTC to local
    //plot (0,1,BLACK); // Hide AM Dot
    showDigit(0,2,(myhours/10)%10,5,clockFont,hhColor); // Show 1st digit of hour
  }
  showDigit(6-x,2,myhours%10,5,clockFont,hhColor); // Always Show 2nd digit of hour
  showDivider (blinkColor);
  showDigit(15,2,(minute()/10)%10,5,clockFont,mmColor); // Show 1st digit of minute
  showDigit(22,2,minute()%10,5,clockFont,mmColor); // Show 2nd digit of minute
  
}
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

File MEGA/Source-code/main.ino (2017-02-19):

// =======================================================================================
// ---- Main nonblocking constant scrolling of message on bottom screens ----
//  scrNum=0 is top portion of bottom screen, 1 is bottom
// By: LensDigital (updated 1/22/2017)
// =======================================================================================
void scrollScreen (char displ, int scrlDelay) {
  if (isInMenu) return;
  if ((unsigned long)millis()-lastScroll[displ] < scrlDelay ) return; // Controlls speed of scrolling
  if (displ) scrolltextlimit (displ,DISPLAY_SPLIT,8,botBuff,scrlDelay);// Bottom part
  else scrolltextlimit (displ,DISPLAY_SPLIT,0,topBuff,scrlDelay); // Top part
  lastScroll[displ]=millis();
}

// =======================================================================================
// ---- Display Current Internal/external Temperature (Screen 1) ----
// By: LensDigital (updated 1/22/2017)
// =======================================================================================
void showTemp(int dispNum){
  if (isInMenu) return;
  //if (showingHum) return;
  if (screenInUse[dispNum] && !showingTemp) return;
  if ((unsigned long)millis()-lastTempShow < NewScreenDelay ) return; // Check if just run this to prevent it from hogging screen space
  if (!showingTemp) {
    showingTemp = true;
    screenInUse[dispNum]=true;
  }
  //if (pauseScroll) return;
  getTemp(1);
  if (tempUpdated) {
    tempUpdated=false;
    //Serial.println (F("Temperature Updated"));
    float tempF = (tempC * 1.8) + 32.0; // Convert internal to Farenheit
    float xtempF = (extTemp * 1.8) + 32.0; // Convert external to Farenheit
    int tempCint = int(tempC +0.5) - tmpOffset;// Convert round off decimal to whole number.
    int tempFint = int(tempF +0.5) - tmpOffset; // Convert round off decimal to whole number.
    int xtempFint = int(xtempF +0.5); // Convert round off decimal to whole number.
    if (extTemp > 100 || extTemp < -50) snprintf(botBuff,sizeof(botBuff), "In Temp: %dF(%dC)",tempFint,tempCint); // only show internal temp
    else snprintf(botBuff,sizeof(botBuff), "Temp(in/out):%dF(%dC)/%dF(%dC)",tempFint,tempCint,xtempFint,extTemp); // Show both internal/external temp
  }
  if (scrollDone[dispNum]) { // Reset permits
      screenInUse[dispNum]=false; // Release Screen queue
      scrollDone[dispNum]=false;
      lastTempShow=millis();
      showingTemp=false;
      tempUpdated=true; // Enable Temp string update for next time
      //Serial.println ("Debug: Done with Temp scroll");
    }
}



// =======================================================================================
// ---- Display Current External Humidity  ----
// By: LensDigital
// =======================================================================================
void showHumidityExt(int dispNum){
  if (!RFRecieved) return;
  if (!isRadioPresent) return;
  if (isInMenu) return;
  if (screenInUse[dispNum] && !showingHum) return;
  if ((unsigned long)millis()-lastHumShow < NewScreenDelay ) return; // Check if just run this to prevent it from hogging screen space
  if (!showingHum) {
    //Serial.println ("Debug: Humidity scroll");
    //snprintf(botBuff,sizeof(botBuff), "DEBUG HUMIDITY",extHum); // Scroll Outside Humidity
    showingHum=true;
    screenInUse[dispNum]=true;
  }
  //if (pauseScroll) return;
  //if (humUpdated) {
  if (tempUpdated) {
    humUpdated =false;
    if (infoOptions & IO_OutHum) { // Option enabled
      if (extHum > 100 || extHum < 1) {
        Serial.println ("Humidity data error");
        snprintf(botBuff,sizeof(botBuff), "Ext Sensor Error"); // Scroll Outside Humidity
      }
      else snprintf(botBuff,sizeof(botBuff), "Humidity %d%%",extHum); // Scroll Outside Humidity
      
    }
  }
  if (scrollDone[dispNum]) { // Reset permits
       screenInUse[dispNum]=false; // Release Screen queue
        scrollDone[dispNum]=false;
        lastHumShow=millis();
        showingHum = false;
        humUpdated=true; // Enable Hum string update for next time
        //Serial.println ("Debug: Done with Humidity scroll");
      }
}
// =======================================================================================
// ---- Display GPS Stats  ----
// By: LensDigital
// =======================================================================================
void scrollGPSStat (int dispNum) {
  if (!GPSEnabled) return;
  if (isInMenu) return;
  if (screenInUse[dispNum] && !showingGPS) return;
  if ((unsigned long)millis()-lastGPSShow < NewScreenDelay ) return; // Check if just run this to prevent it from hogging screen space
  if (!showingGPS) {
    //Serial.println (F("Debug: GPS Stats scroll"));
    showingGPS=true;
    screenInUse[dispNum]=true;
  }
  snprintf(topBuff,sizeof(topBuff), "GPS time updated:%s",msgbuffer);
  if (scrollDone[dispNum]) { // Reset permits
       screenInUse[dispNum]=false; // Release Screen queue
       scrollDone[dispNum]=false;
       lastGPSShow=millis();
       showingGPS = false;
       //Serial.println ("Debug: Done with GPS scroll");
      }
}
// =======================================================================================
// ---- Display Remote Sensor Stats  ----
// By: LensDigital
// =======================================================================================
void scrollSnsStat (int dispNum) {
  if (!RFRecieved) return; // We never got transmission
  if (!isRadioPresent) return;
  if (isInMenu) return;
  if (screenInUse[dispNum] && !showingRF) return;
  if ((unsigned long)millis()-lastRFStatShow < NewScreenDelay ) return; // Check if just run this to prevent it from hogging screen space
  if (!showingRF) {
    //Serial.println (F("Debug: RF Stats scroll"));
    showingRF=true;
    screenInUse[dispNum]=true;
  }
   // Split batter 3 digit voltage into separate digits
    byte first=sBatt/100; // Thousand
    byte scnd =(sBatt%100)/10;
    byte third=sBatt%10;
    if ((unsigned long)millis()-lastRFEvent < RFTimeout*60000 ) 
      snprintf(topBuff,sizeof(topBuff), "Sns data rcv at %02d:%02d,BAT:%d.%d%dV",hour(myTZ.toLocal(last_RF, &tcr)),minute(last_RF),first,scnd,third );
    else 
      snprintf(topBuff,sizeof(topBuff), "Sns data rcv %02d/%02d at %02d:%02d,BAT:%d.%d%dV",month(myTZ.toLocal(last_RF, &tcr)),day(myTZ.toLocal(last_RF, &tcr)), hour(myTZ.toLocal(last_RF, &tcr)),minute(last_RF),first,scnd,third );
   if (scrollDone[dispNum]) { // Reset permits
       screenInUse[dispNum]=false; // Release Screen queue
       scrollDone[dispNum]=false;
       lastRFStatShow=millis();
       showingRF = false;
       //Serial.println ("Debug: Done with RF scroll");
      }
}
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

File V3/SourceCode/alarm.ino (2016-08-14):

// =======================================================================================
// ---- Process Alarm Function ----
// By: LensDigital, WPB
// =======================================================================================
void procAlarm(byte alrmnum) {
  if (isInMenu) return; // Do not sound alarm if changing settings
    //if (digitalRead(SET_BUTTON_PIN) == LOW) processSetButton(); // Poll Set Button, that will reArm (cancel for today) alarm
    if ( buttonsStatus[SET_BUTTON] == B_PRESSED ) processSetButton(); // If Set Button was pressed, snooze
    if (alarmon[alrmnum] & 128){ // Is global alarm switch on? (1st byte is set)
      // ==== Begin alarm LED indicator ====
      if ( snoozeTime[alrmnum]==10) {
        if ( alarmon[alrmnum] & weekdays[weekday(LOCAL_TZ)] ) plot (29*alrmnum+1,15,RED); // Show dot in Orange, indicating that alarm is set for current day
        else   plot (29*alrmnum+1,15,GREEN); // No alarm today so show green dot in lower right corner 
      } 
      else plot (29*alrmnum+1,15,ORANGE); // Show dot in RED if snoozing (Maybe do blinking in the future too)
      // ==== END alarm LED indicator ====
      
      if (soundAlarm[alrmnum]) playAlarm(alrmnum);
      // ==== Begin Snooze Check ====
      else {
        // Are We Snoozing?
        if ( snoozeTime[alrmnum]!=10 ) { // Snooze was pressed
         // Is it time reset Snooze?
         if ( (minute()%10) == snoozeTime[alrmnum]) {
           soundAlarm[alrmnum]=true; // Check last digit of current minute
           if (alrmToneNum[alrmnum]<6) alrmVol[alrmnum]=7; // Reset Alarm Volume
           else alrmVol[alrmnum]=0;
         }
      }
       // ==== End Snooze Check ====
      // Maybe it's time to sound alarm for the first time at specified time?
      else
       if (!interruptAlrm[alrmnum]) // Has not been interrupted, takes care if alarm was canceled within 1st minute
         /*
         if ( (alarmon[alrmnum] == 2) && ( (weekday() == 1) || (weekday () == 7) ) ) ;// Do nothing, cause it's weekend and alarm was set to weekday
         else // It's Either Daily alarm or we are in Mon-Fri range
         */
         if ( alarmon[alrmnum] & weekdays[weekday(LOCAL_TZ)] ) // Alarm is scheduled for this day!
          if ( (myhours==alrmHH[alrmnum]) && ( minute()==alrmMM[alrmnum])  ) {
            if (alrmnum==0) { // It's first alarm processor
              soundAlarm[1]=false; //Innterrupts 2nd alarm if it's playing
              snoozeTime[1]=10; // Disable snooze for 2nd alarm
            }
            else { // It's first alarm processor
              soundAlarm[0]=false; //Innterrupts 1st alarm if it's playing
              snoozeTime[0]=10; // Disable snooze for 1st alarm
            }
           soundAlarm[alrmnum]=true; // If it's time to sound alarm!
          }
      }
  }
}



// =======================================================================================
// ---- Play Alarm Sound ----
// By: LensDigital
// =======================================================================================
void playAlarm(byte alrmnum) {
  turnOffRadio(); // Disable RFM
   if (interruptAlrm[alrmnum]) {
//      wave.stop();
     return; // Alarm was interrupted with button, exit
  }
  char myString[11];
  snprintf(myString,sizeof(myString), "ALRM%d.WAV",alrmToneNum[alrmnum]); // Make Alarm Filename
  playalarmfile(myString,alrmnum);
  
}
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

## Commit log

2016-03-01 Uploaded design files
    [XRONOS_CLOCK_V2.1.brd, XRONOS_CLOCK_V2.1.sch]
2016-08-08 Arduino Version Note
2016-08-08 Avrdude and Arduino version notice
2016-08-14 Fixes
    Fixed incorrect time display in 12hr mode.
    [alarm.ino, main.ino, menus.ino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]
2016-11-03 Bug fixes
    Fix for RFM12b radio.
    Fix for EEPROM Reset menu item.
    [menus.ino, xronos3.h, xronos3.ino]
2016-11-03 RFM12b Fix
    Modified pin mappings for IRQ, etc.
    [RFM12B.h]
2016-11-07 V3.05
    Fix Radio Stats display and RF indicator
    Fix QuickMenu Alarm announcement
    [xronos3.ino]
2016-11-07 V3.05 Bug fixes
    V05: Fix Radio stats, fix QuickMenu (alarm not annoused)
    [radio.ino, xronos3.h]
2016-11-07 V3.06 (Radio Stats)
    Updated to show datestamp of last radio recieve if it's been too long
    since last transmission.
    [main.ino, xronos3.ino]
2016-11-07 Fix Github garbage
    Github for desktop completely messed up my code :(
    [xronos3.ino]
2016-11-17 V 3.08
    Fixed ext. temperature display bug and few others.
    Replaced TH02 with SI7021 sensor (for Xronos 3 boards).
    [HT1632.h, audio.ino, main.ino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]
2016-11-17 Si7021 Sensor replaced TH02
2017-02-08 V8 bug fixes, new features
    Major rewrite of all message scrolling functions.
    Display for Radio status and sensor battery level.
    Attempt at fixing temperature bug
2017-02-09 V9: Fix temperature sensor
    Fix external (radio) sensor temperature not showing correctly.
2017-02-09 V9
    External Tempreature sensor fix
    [radio.ino, xronos_mega_R1.ino]
2017-02-19 V10
    Fix for temperature/humidity stats. Sender ID Check
    [main.ino, radio.ino, xronos_mega.h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]
2017-02-26 V.11
    User now has control over what to show on scrolling display. New menu
    option to show or not RF sensor stats.
2017-04-01 V 3.09
    - Possible Fix for incorrect temperature from external sensor.
    - Added V3 hex firmware version compatible with Xronos 2 Clock
    [radio.ino, xronos3.h, xronos3.ino]

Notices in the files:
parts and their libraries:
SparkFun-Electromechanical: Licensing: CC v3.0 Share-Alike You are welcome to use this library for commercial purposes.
